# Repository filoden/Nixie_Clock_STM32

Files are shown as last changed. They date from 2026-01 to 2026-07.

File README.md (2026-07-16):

# Nixie_Clock_STM32

An STM32-based **Nixie-tube alarm clock** (HH:MM) with audio, SD storage, and a custom enclosure. 
Repository still in developement.

> ⚠️ **High Voltage Warning**
> Nixie tubes require a high-voltage supply (~170VDC for IN-12 used in this project). Basic HV safety knowledge is necessary to avoid injury and or death.

---

## Project Snapshot

**Design tools:** KiCad (PCB), STM32CubeMX / STM32CubeIDE (firmware), SolidWorks (enclosure)

**Repo structure**
- `Current Iteration/` – active hardware + firmware
  - `Current Iteration/Enclosure`
  - `Current Iteration/STM32 Project Files and Code`
  - `Current Iteration/Schematic Layout & PCB`
- `Old_Versions/` – previous spins / archived work

---

## Features

### Hardware / Electronics (status)
**In development**
- low power / battery-power mode
- Oscillator bring-up / stability checks

**Tested (prototype version)**
- Capacitive touch input

**Finalized**
- I2S audio communication
- 5V → 12V boost 
- SPI / I2C communication
- SD Card Interface
- Rotary encoders
- 5V → 3.3V LDO
- Audio output: driving a 4Ω speaker through the MAX98567A (except for bulk cap)
- SD audio file reading

---

## Hardware Overview (high level)

- **MCU:** STM32G0B1RETx6
- **UX/UI:** rotary encoder(s) (One encouder includes a push button), capacitive touch
- **Timekeeping:** STM32 RTC + external LSE oscillator
- **Storage:** microSD over SPI (FatFs)
- **Audio:** I2S to class-D amp (MAX98567A) → 4Ω speaker
- **Driving Nixie Tubes** STM MCU drives serial into a 12V level shifter which drives HV5622PG chips. These chips switch the tubes using an external 170V DC source.
- **Capacitive touch senor** Conductive edge banding surrounds large portions of controller. CAP1206 IC interprets changes in banding capacitance and communicates over I2C to MCU.
- **Power:**
  - USB-C 5V input (mechanical + ESD considerations)
  - 5V enters Linear low-dropout regulator -> 3.3V 
  - 3.3V rail for logic
  - HV rail for Nixie tubes (external boost converter)
  - Battery backup is used for logic, oscillator, amplifier, and capacitive touch sensor in the event of 5V loss
  - Battery and 3.3V power is controlled using NID5100, low-forward voltage drop diodes.
### Schematic Preview
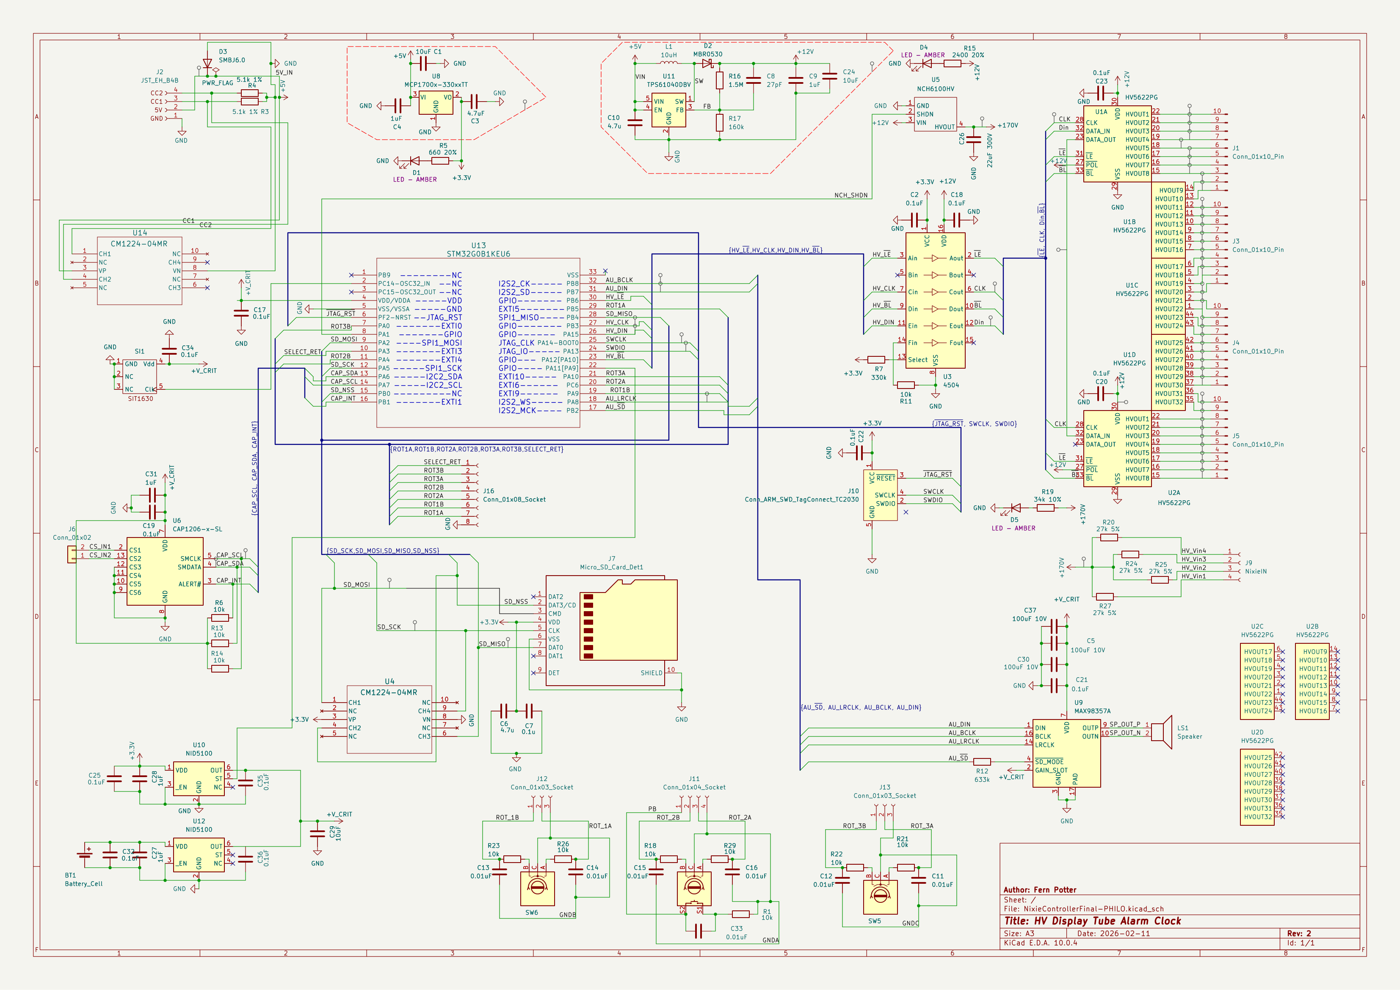
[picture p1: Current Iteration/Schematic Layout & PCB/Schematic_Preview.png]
Schematic

### Block Diagram
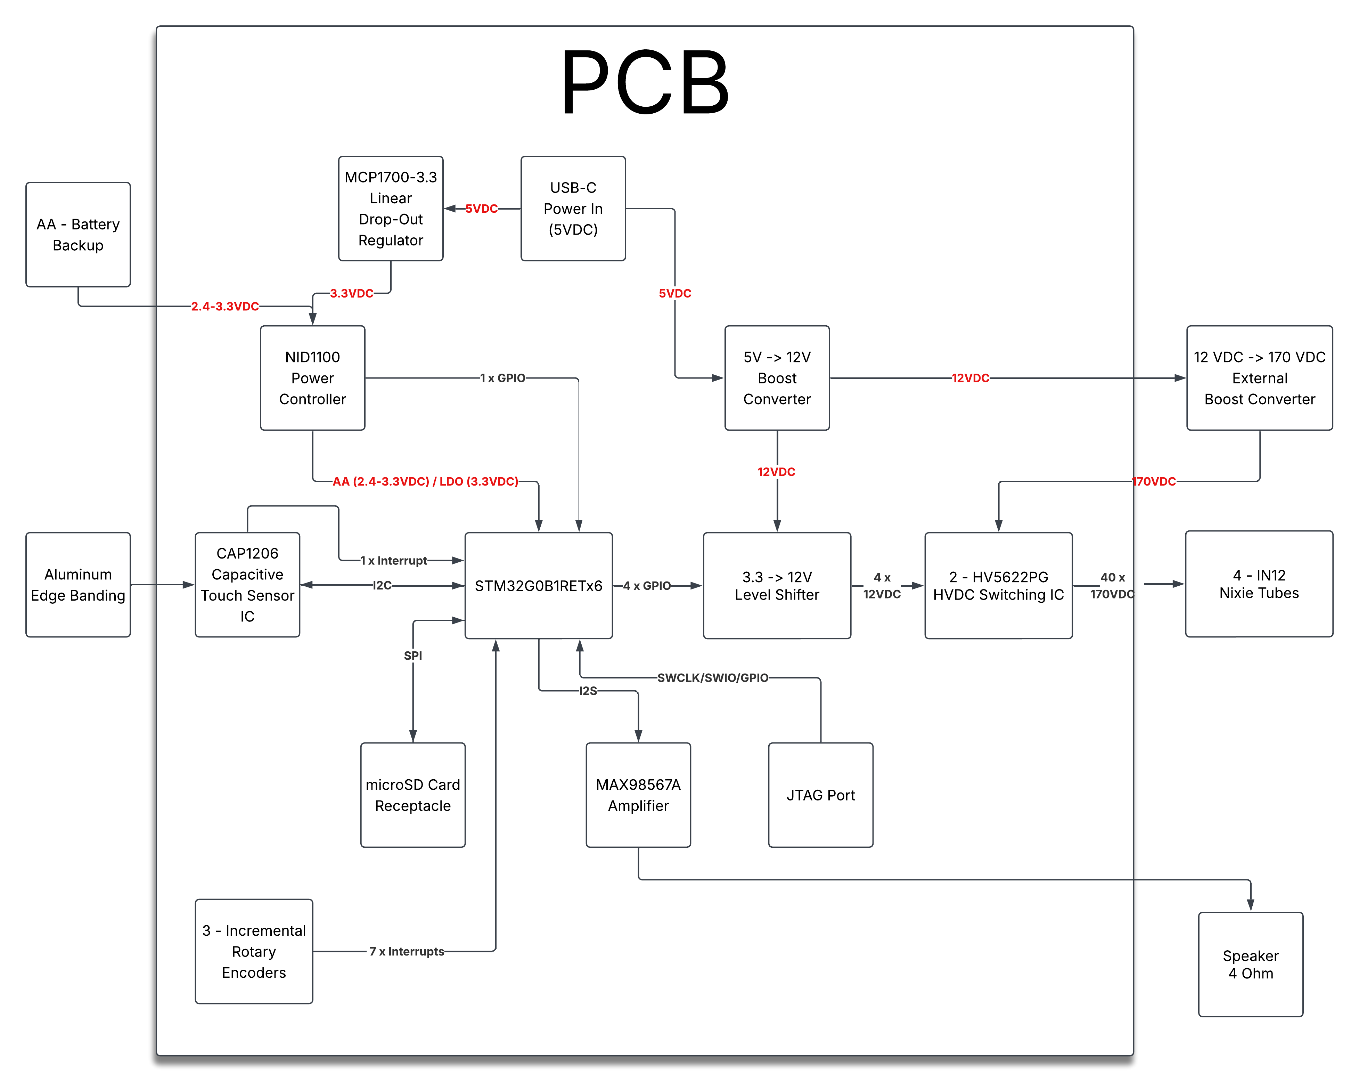
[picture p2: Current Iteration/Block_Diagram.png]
Block Diagram

#### Notes:
- All Power lines are written in red text
- Arrow direction denotes either flow of power or data (although JTAG should be bidirectional)
- Ground for IN12 Tubes is omitted
---

## Firmware 
### Build / Flash 
1. Open the firmware project in **STM32CubeIDE**.
2. Confirm CubeMX-generated peripherals match the board wiring (SPI for SD, I2S for audio, GPIO/EXTI for inputs). Make sure to include separate driver files for FATFS (Provided by CubeMX). 
4. Build + flash via **ST-LINK**.
5. To avoid frustration, bring-up in this order:
### Firmware Development (Status):
### Integration:
**1. UI FSM**
- UI is structured as an FSM. Programmatically each input will trigger a user-input function for each respective input (knob A turns CC, knob B turns C, etc.. Each function consists of a long switch case which maps the appropriate response to an input for a given state. Relevant code is in UserInterface source and header files. FSM can be seen below.
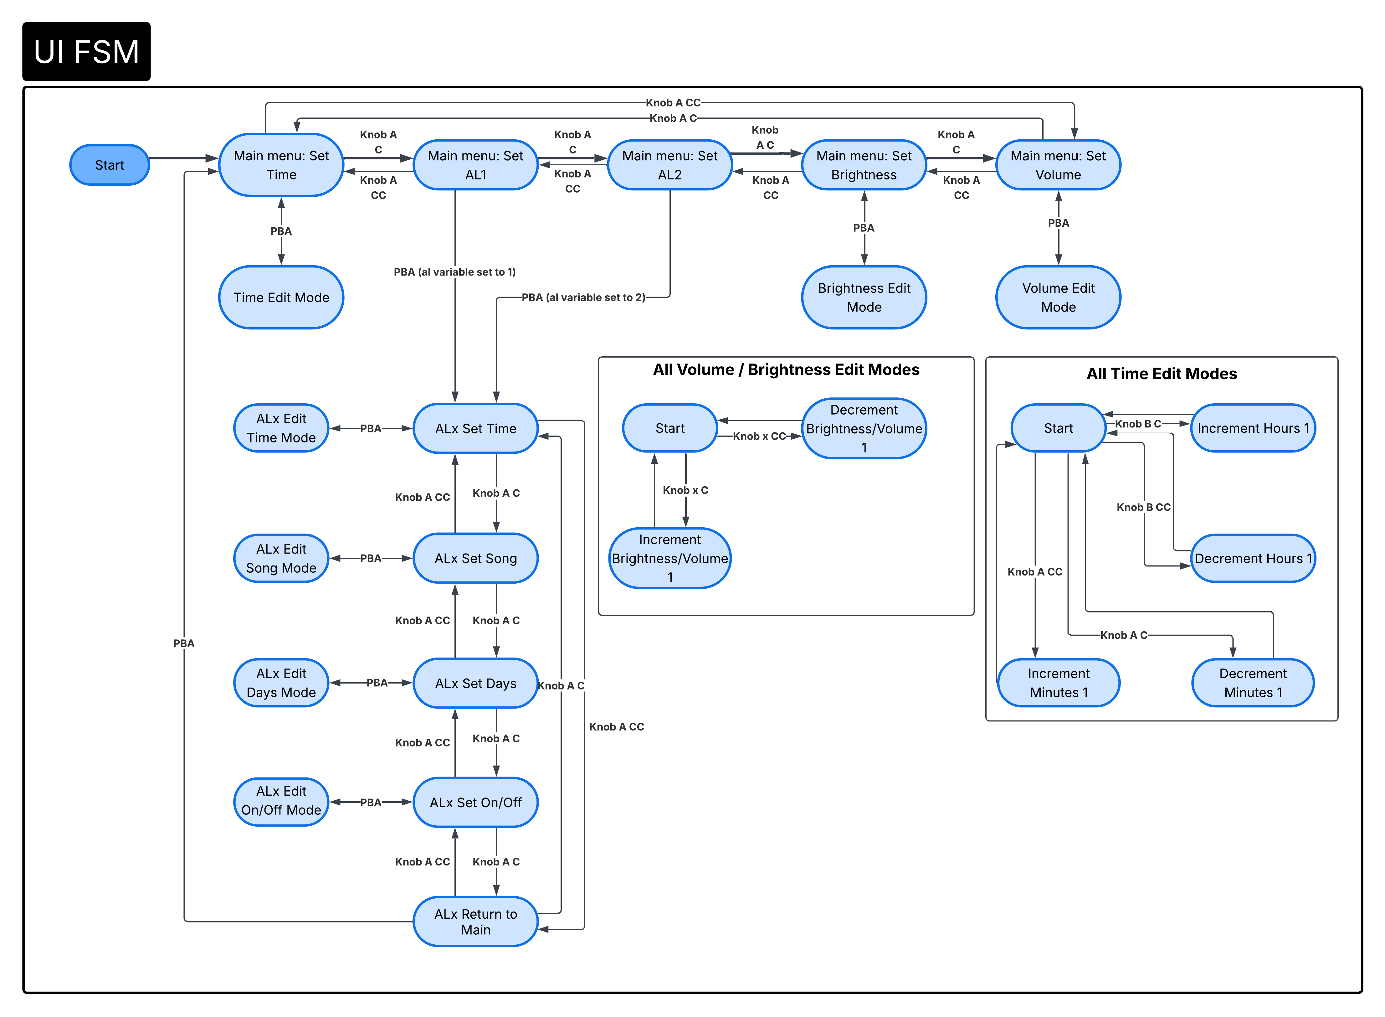
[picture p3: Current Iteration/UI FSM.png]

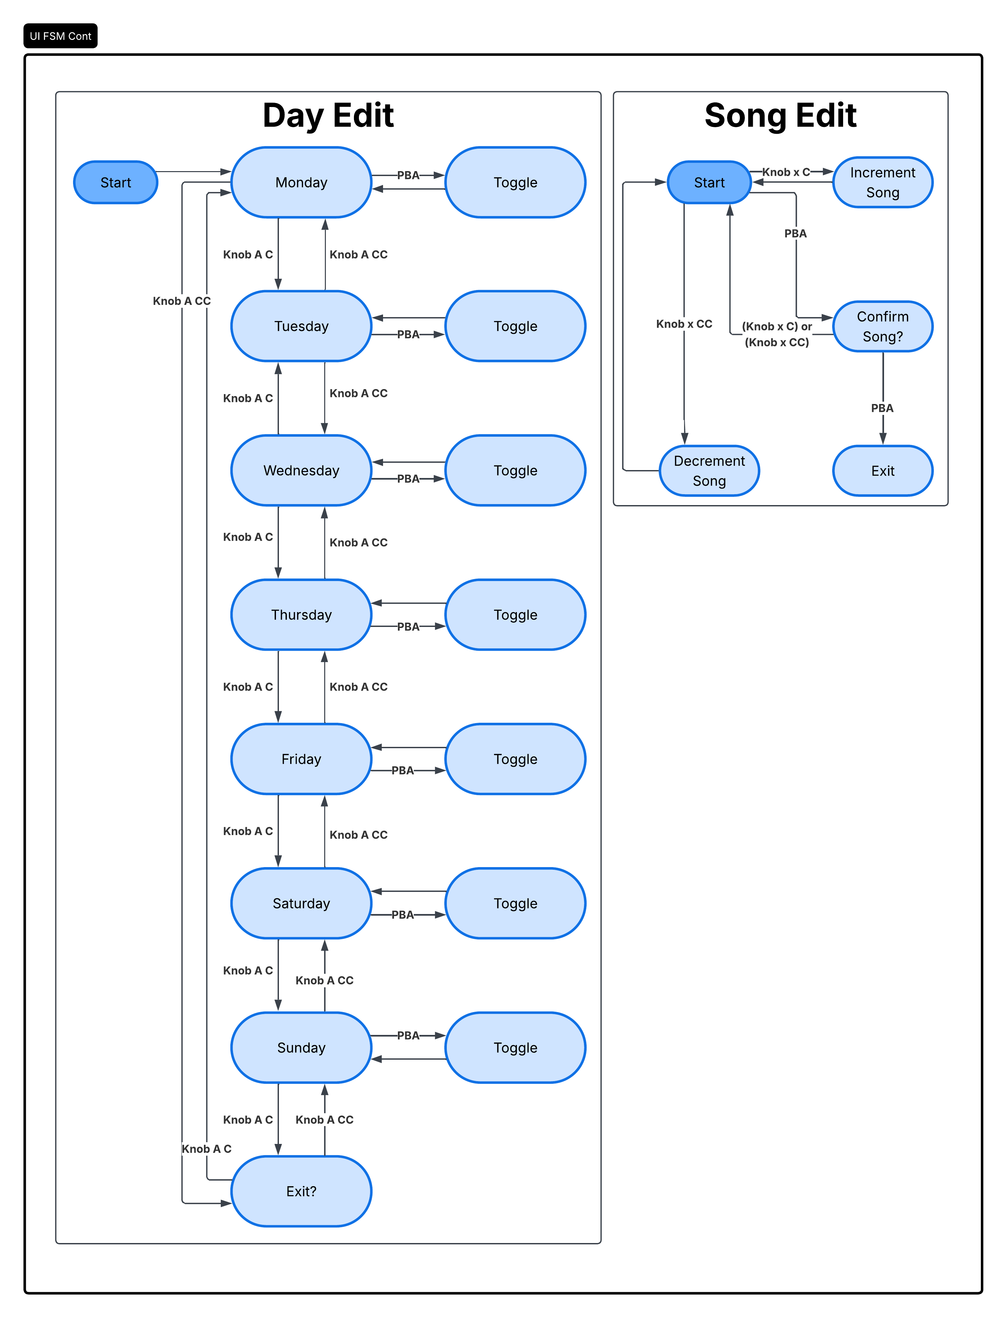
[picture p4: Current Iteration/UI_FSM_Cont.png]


**Notes to come:**

**2. DMA music playing**

**3. SD card interface**

**4. Capacitive touch sensor**

**5. Music FIle Parsing**

### In development:

**6. Nixie driver control logic**

- Nixie tubes require 170VDC switching. Thankfully, Many old display tubes and other vintage electronics require high voltage DC. Since there is still demand for this technology an old (relatively speaking) serial to parallel high voltage switching IC known as the HV5622PG is still in production. This $8 chip can handle up to 250VDC and requires a ridiculous 12V logic level. The Nixie driver control logic tells this chip which digits to turn on. Importantly, it must also make sure that no more than one digit is driven at a time, as this can easily destroy the tube. Additionally, it is necesary to include PWM control to allow for dimming, and to be easily accessible by other parts of the code.
- Requirements: 
  - Checks to ensure there is no double digit driving
  - Dimming Control
  - Simple function call

**7. Low-Power (Blackout) Handling**

Requirements:
  - Set Pins to LOW (Remove any Pullups as well): Nixie Driving GPIO, JTAG, SD_CARD, CAP1206, knobs B/C
  - Following Interfaces to remain as normal: MAX98357A
  - Sense Power-outage via ST pin on NID5100
  - Be able to play low power alarm song stored solely in on-chip memory

**8. New external LSE with RTC implementation**

Requirements:
  - Initialization
  - Maintain RTC control through momentary resets
  - Calibration (?)
---

## PCB Development
Current version consists of a single main board with three separate smaller boards (separated by user) for the rotary encoder circuitry.
- **V1 PCB:** learning spin (many layout mistakes)
- **V2 PCB:** More fully built out, includes all relevent IO.
- **V3 PCB:** pending completion of wiring/programming development - most up to date version located in current iteration. 
### To-do
- External LSE oscillator testing
- Add AA discharge protection
- Connext NCH6100HV Directly to 5V rail instead of 12V
- Much more
### PCB Preview
**V3 PCB:**
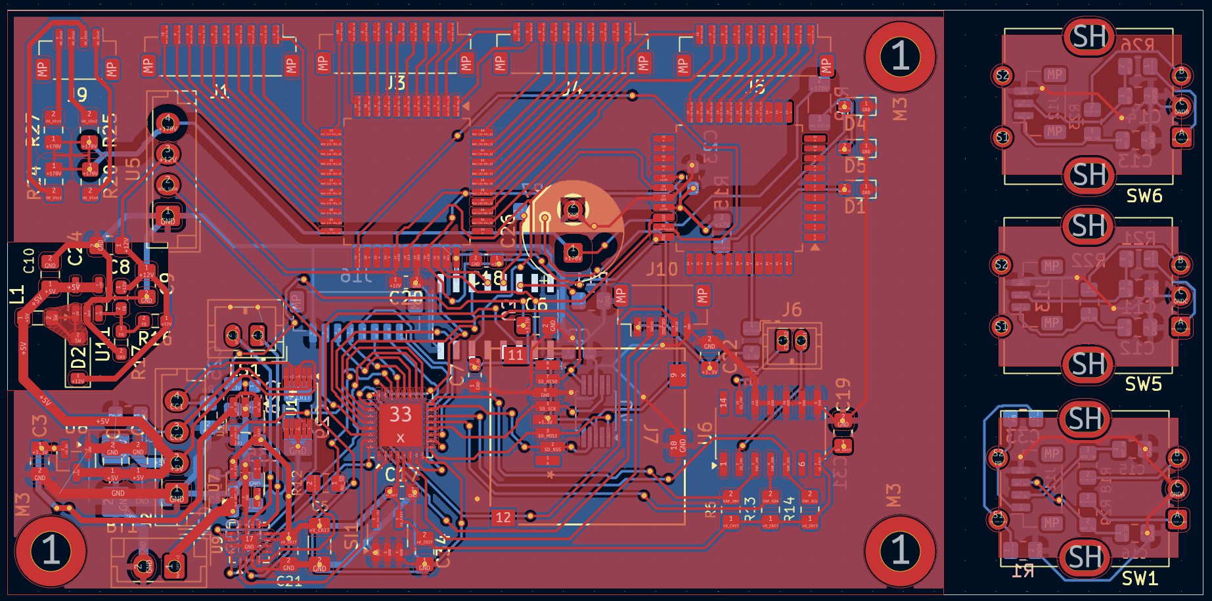
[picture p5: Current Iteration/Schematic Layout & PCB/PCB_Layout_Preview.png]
Current Revision
 
---

## Enclosure Development

### Current plan
- Mostly **wood** enclosure in **two glued halves**
- Two halves are **mostly symmetric** and CNC-machinable from a single board  
  - Best results: mill one thick piece and split for mirrored grain (book-matching)
- **Front + back edges:** laser-cut **aluminum edge banding** (strength + aesthetics), glued in place
- **Back plate:** thicker aluminum for rotary encoders + USB-C inlet
- **Front plate:** 1/8" glass (waterjet preferred; hand-fab possible) with a grey tint

### To-do
- Vector files: back plate, glass face, edge banding
- Finalize BOM
- Investigate use of waterjet for glass face
### Enclosure Preview
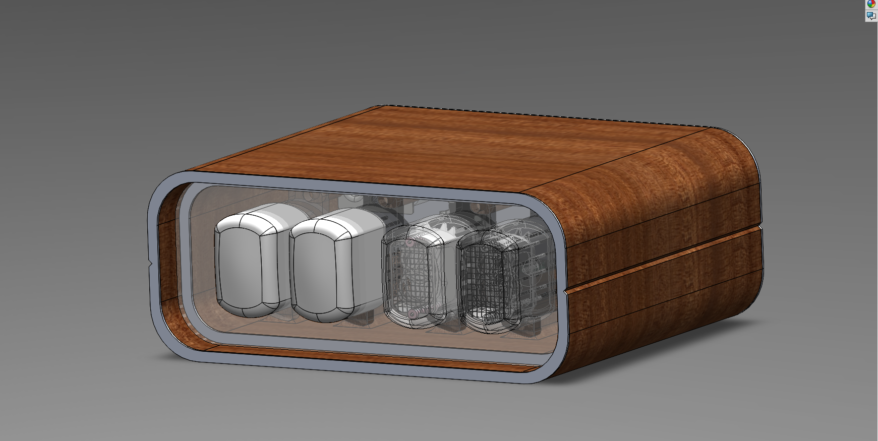
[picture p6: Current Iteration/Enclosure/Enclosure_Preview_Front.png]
Enclosure Front

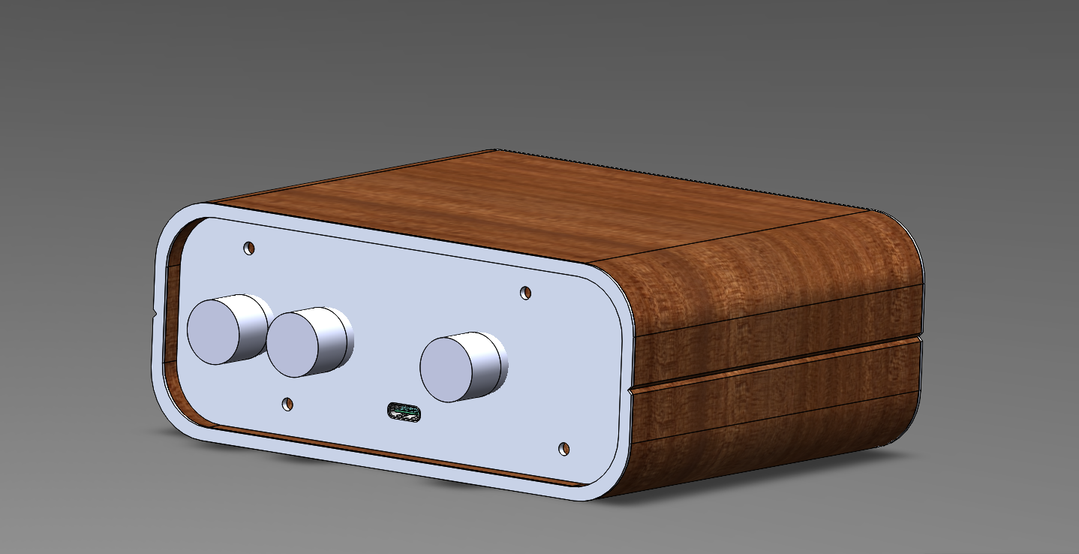
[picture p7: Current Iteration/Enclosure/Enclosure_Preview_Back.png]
Enclosure Back

---

## BOM
- PCB BOM currently matches latest revision
- Enclosure BOM is out of date

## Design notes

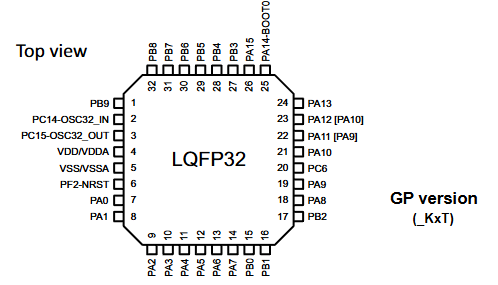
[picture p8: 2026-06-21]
Useful Documents/Pinout_STM32G0B1RET6-LQFP32.png

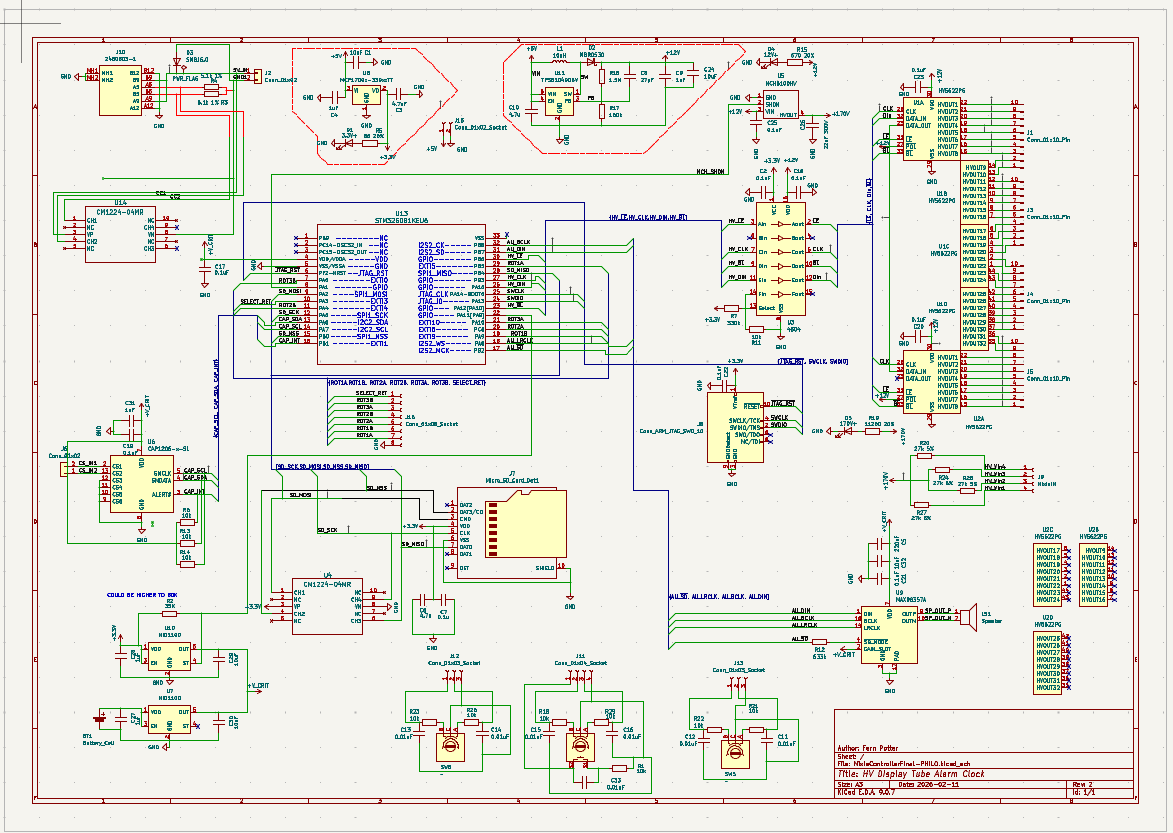
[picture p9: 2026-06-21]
Current Iteration/Schematic Layout & PCB/Schematic_Layout_Preview.png

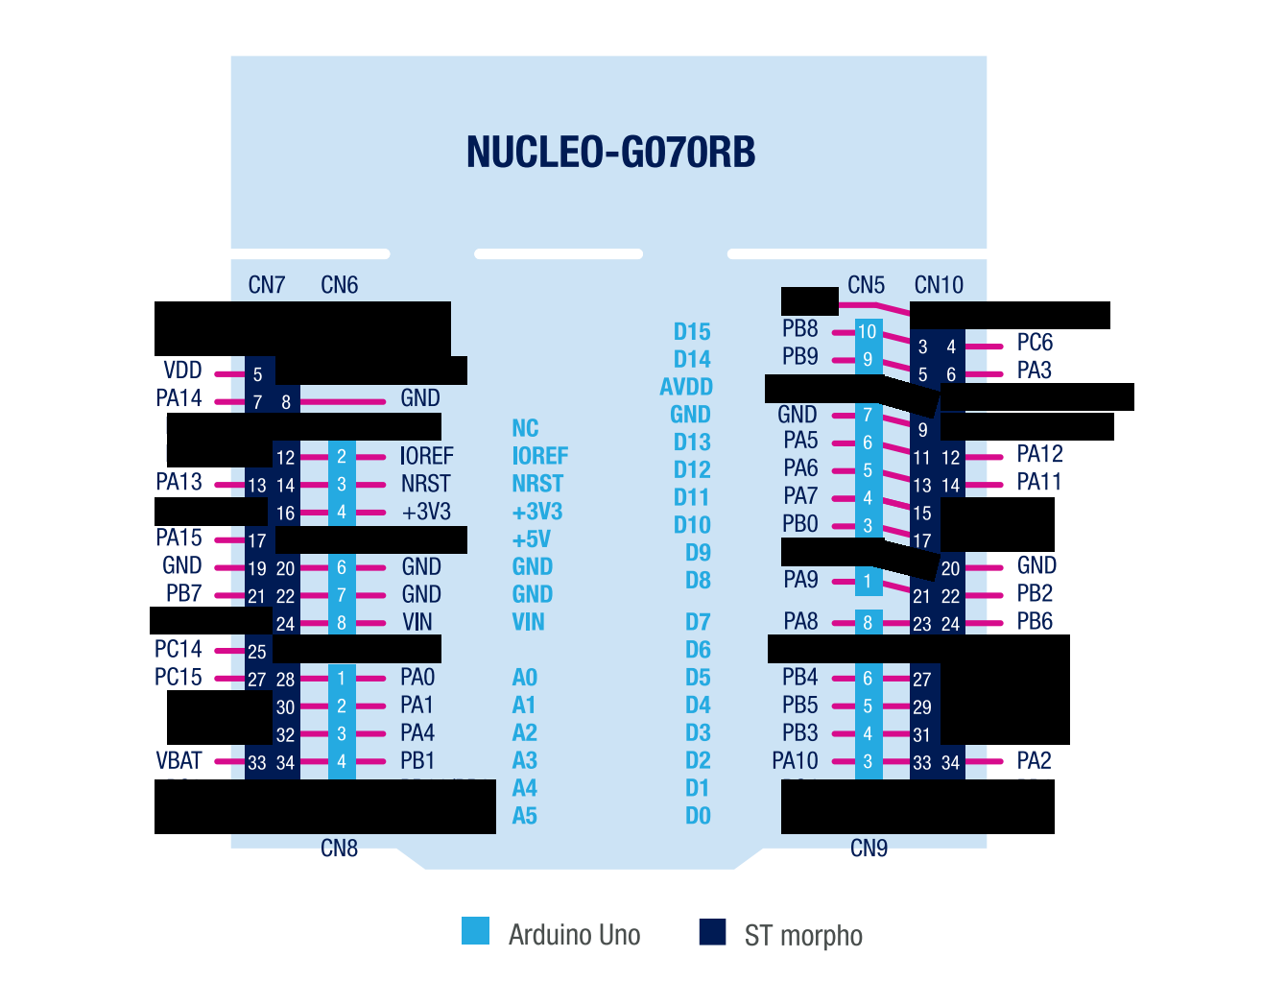
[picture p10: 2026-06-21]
Useful Documents/Pinout_Nucleo_G0B1RE.png

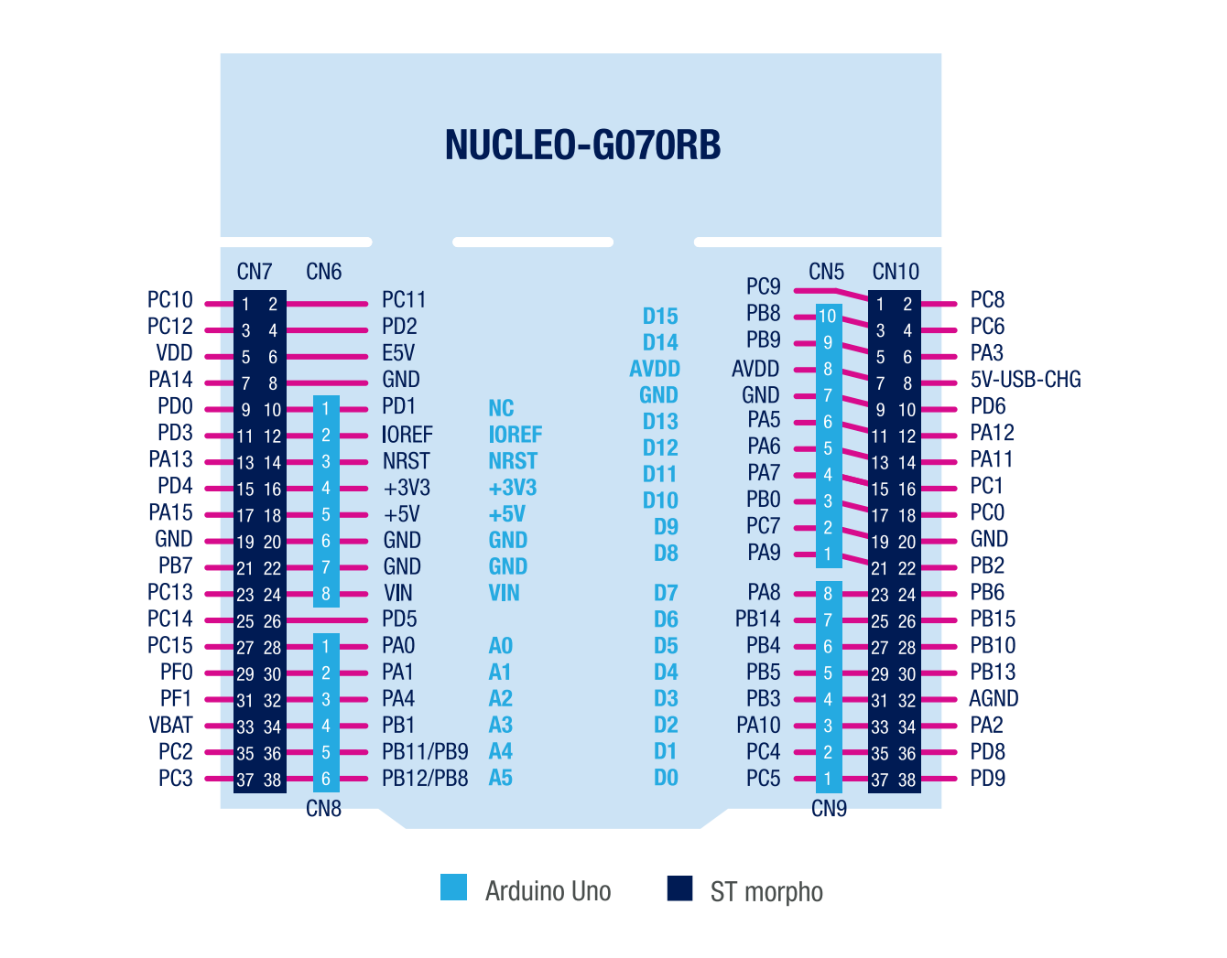
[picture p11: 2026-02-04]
Useful Documents/Screenshot 2026-01-30 183604.png

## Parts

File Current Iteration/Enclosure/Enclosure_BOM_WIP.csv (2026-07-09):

Quantity | Part
1 | 4x6x10 (inches) hard wood of choice
1 | 6x12 1/16 (inches) aluminum sheeting
4 | IN12 New Old Stock Nixie Tubes

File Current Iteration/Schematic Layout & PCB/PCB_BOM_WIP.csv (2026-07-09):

Reference | Qty | Value | DNP | Exclude from BOM | Exclude from Board | Footprint | Datasheet
BT1 | 1 | Battery_Cell |  |  |  | Connector_JST:JST_EH_B2B-EH-A_1x02_P2.50mm_Vertical | ~
C1,C29,C30 | 3 | 10uF |  |  |  | Capacitor_SMD:C_0805_2012Metric_Pad1.18x1.45mm_HandSolder | ~
C2,C17,C18,C19,C21,C22,C25 | 7 | 0.1uF |  |  |  | Capacitor_SMD:C_0805_2012Metric_Pad1.18x1.45mm_HandSolder | ~
C3 | 1 | 4.7uF |  |  |  | Capacitor_SMD:C_0805_2012Metric_Pad1.18x1.45mm_HandSolder | ~
C4,C9,C27,C28,C31 | 5 | 1uF |  |  |  | Capacitor_SMD:C_0805_2012Metric_Pad1.18x1.45mm_HandSolder | ~
C5 | 1 | 220uF |  |  |  | Capacitor_SMD:C_1206_3216Metric_Pad1.33x1.80mm_HandSolder | ~
C6 | 1 | 4.7u |  |  |  | Capacitor_SMD:C_1206_3216Metric_Pad1.33x1.80mm_HandSolder | ~
C7 | 1 | 0.1u |  |  |  | Capacitor_SMD:C_0805_2012Metric_Pad1.18x1.45mm_HandSolder | ~
C8 | 1 | 27pF |  |  |  | Capacitor_SMD:C_0805_2012Metric_Pad1.18x1.45mm_HandSolder | ~
C10 | 1 | 4.7u |  |  |  | Capacitor_SMD:C_0805_2012Metric_Pad1.18x1.45mm_HandSolder | ~
C11,C12,C13,C14,C15,C16,C33 | 7 | 0.01uF |  |  |  | Capacitor_SMD:C_0805_2012Metric_Pad1.18x1.45mm_HandSolder | ~
C20,C23 | 2 | 0.1uF |  |  |  | Capacitor_SMD:C_1808_4520Metric_Pad1.72x2.30mm_HandSolder | ~
C24,C32 | 2 | 10uF |  |  |  | Capacitor_SMD:C_1206_3216Metric_Pad1.33x1.80mm_HandSolder | ~
C26 | 1 | 22uF 300V |  |  |  | Capacitor_THT:CP_Radial_D8.0mm_P3.50mm | ~
D1 | 1 | 3.3V+ |  |  |  | LED_SMD:LED_0603_1608Metric_Pad1.05x0.95mm_HandSolder | ~
D2 | 1 | MBR0530 |  |  |  | Diode_SMD:D_SOD-123 | http://www.mccsemi.com/up_pdf/MBR0520~MBR0580(SOD123).pdf
D3 | 1 | SMBJ6.0 |  |  |  | Diode_SMD:D_SMB | ~
D4 | 1 | 12V+ |  |  |  | LED_SMD:LED_0603_1608Metric_Pad1.05x0.95mm_HandSolder | ~
D5 | 1 | 170V+ |  |  |  | LED_SMD:LED_0603_1608Metric_Pad1.05x0.95mm_HandSolder | ~
J1,J3,J4,J5 | 4 | Conn_01x10_Pin |  |  |  | Connector_JST:JST_SH_BM10B-SRSS-TB_1x10-1MP_P1.00mm_Vertical | ~
J2 | 1 | Conn_01x02 |  |  |  |  | ~
J6 | 1 | Conn_01x02 |  |  |  | Connector_JST:JST_EH_B2B-EH-A_1x02_P2.50mm_Vertical | ~
J7 | 1 | Micro_SD_Card_Det1 |  |  |  | footprints:MEM2061-01-188-00-A_GCT | https://datasheet.lcsc.com/lcsc/2110151630_XKB-Connectivity-XKTF-015-N_C381082.pdf
J8 | 1 | Conn_ARM_JTAG_SWD_10 |  |  |  | Connector_JST:JST_SH_BM05B-SRSS-TB_1x05-1MP_P1.00mm_Vertical | http://infocenter.arm.com/help/topic/com.arm.doc.ddi0314h/DDI0314H_coresight_components_trm.pdf
J9 | 1 | NixieIN |  |  |  | Connector_JST:JST_SH_BM04B-SRSS-TB_1x04-1MP_P1.00mm_Vertical | ~
J10 | 1 | 2480803-1 |  |  |  | Connector_USB:24808031 | https://www.te.com/de/product-2480803-1.datasheet.pdf
J11 | 1 | Conn_01x04_Socket |  |  |  | Connector_JST:JST_SH_BM04B-SRSS-TB_1x04-1MP_P1.00mm_Vertical | ~
J12,J13 | 2 | Conn_01x03_Socket |  |  |  | Connector_JST:JST_SH_BM03B-SRSS-TB_1x03-1MP_P1.00mm_Vertical | ~
J15 | 1 | Conn_01x02_Socket |  |  |  | Connector_JST:JST_EH_B2B-EH-A_1x02_P2.50mm_Vertical | ~
J16 | 1 | Conn_01x08_Socket |  |  |  | Connector_JST:JST_SH_BM08B-SRSS-TB_1x08-1MP_P1.00mm_Vertical | ~
L1 | 1 | 10uH |  |  |  | Inductor_SMD:L_0805_2012Metric_Pad1.05x1.20mm_HandSolder | ~
LS1 | 1 | Speaker |  |  |  | Connector_JST:JST_PH_B2B-PH-K_1x02_P2.00mm_Vertical | ~
R1,R6,R11,R13,R14,R18,R21,R22,R23,R26,R29 | 11 | 10k |  |  |  | Resistor_SMD:R_0805_2012Metric_Pad1.20x1.40mm_HandSolder | ~
R2 | 1 | 35K |  |  |  | Resistor_SMD:R_0805_2012Metric_Pad1.20x1.40mm_HandSolder | ~
R3,R4 | 2 | 5.1k 1% |  |  |  | Resistor_SMD:R_0805_2012Metric_Pad1.20x1.40mm_HandSolder | ~
R5 | 1 | 86 20% |  |  |  | Resistor_SMD:R_0805_2012Metric_Pad1.20x1.40mm_HandSolder | ~
R7 | 1 | 330k |  |  |  | Resistor_SMD:R_0805_2012Metric_Pad1.20x1.40mm_HandSolder | ~
R12 | 1 | 633k |  |  |  | Resistor_SMD:R_0805_2012Metric_Pad1.20x1.40mm_HandSolder | ~
R15 | 1 | 670 20% |  |  |  | Resistor_SMD:R_0805_2012Metric_Pad1.20x1.40mm_HandSolder | ~
R16 | 1 | 1.5M |  |  |  | Resistor_SMD:R_0805_2012Metric_Pad1.20x1.40mm_HandSolder | ~
R17 | 1 | 160k |  |  |  | Resistor_SMD:R_0805_2012Metric_Pad1.20x1.40mm_HandSolder | ~
R19 | 1 | 11200 20% |  |  |  | Resistor_SMD:R_0805_2012Metric_Pad1.20x1.40mm_HandSolder | ~
R20,R24,R25,R27 | 4 | 27k 5% |  |  |  | Resistor_SMD:R_0805_2012Metric_Pad1.20x1.40mm_HandSolder | ~
SW1,SW5,SW6 | 3 | ~ |  |  |  | Rotary_Encoder:RotaryEncoder_Bourns_Vertical_PEC12R-3x17F-Sxxxx | kicad-embed://PEC11J.pdf,kicad-embed://pec16.pdf
U1,U2 | 2 | HV5622PG |  |  |  | Package_QFP:PQFP-44_10x10mm_P0.8mm | https://ww1.microchip.com/downloads/aemDocuments/documents/OTH/ProductDocuments/DataSheets/20005854A.pdf
U3 | 1 | 4504 |  |  |  | footprints:SOIC-16_ONS | http://www.ti.com/lit/ds/symlink/cd4504b.pdf
U4,U14 | 2 | CM1224-04MR |  |  |  | Package_SO:MSOP-10_3x3mm_P0.5mm | CM1224-04MR
U5 | 1 | NCH6100HV |  |  |  | Connector_JST:JST_EH_B4B-EH-A_1x04_P2.50mm_Vertical | kicad-embed://NIXIE-Power-Supply-Datasheet-EN-v1.0.0.pdf
U6 | 1 | CAP1206-x-SL |  |  |  | Package_SO:SOIC-14_3.9x8.7mm_P1.27mm | http://ww1.microchip.com/downloads/en/DeviceDoc/00001567B.pdf
U7,U10 | 2 | NID1100 |  |  |  | Package_TO_SOT_SMD:SC-74A-5_1.55x2.9mm_P0.95mm | https://assets.nexperia.com/documents/data-sheet/NID1100.pdf
U8 | 1 | MCP1700x-330xxTT |  |  |  | Package_TO_SOT_SMD:SOT-23 | http://ww1.microchip.com/downloads/en/DeviceDoc/20001826D.pdf
U9 | 1 | MAX98357A |  |  |  | Package_DFN_QFN:TQFN-16-1EP_3x3mm_P0.5mm_EP1.23x1.23mm | https://www.analog.com/media/en/technical-documentation/data-sheets/MAX98357A-MAX98357B.pdf
U11 | 1 | TPS61040DBV |  |  |  | Package_TO_SOT_SMD:SOT-23-5 | http://www.ti.com/lit/ds/symlink/tps61040.pdf
U13 | 1 | STM32G0B1KEU6 |  |  |  | Package_DFN_QFN:UFQFPN-32-1EP_5x5mm_P0.5mm_EP3.5x3.5mm | https://www.st.com/resource/en/datasheet/stm32g0b1cc.pdf

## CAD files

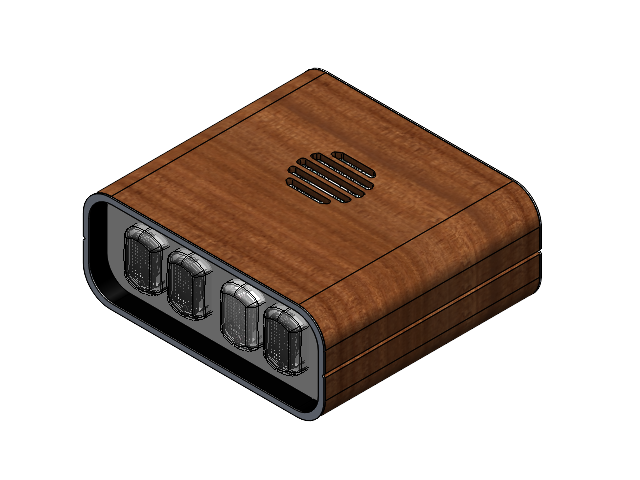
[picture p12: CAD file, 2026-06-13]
Current Iteration/Enclosure/Enclosure.SLDASM
IN-12 nixie tube glass body.STEP x 4
IN-12 nixie tube pin.STEP x 48
IN-12 nixie tube anode grid.STEP x 4
IN-12 nixie tube 0 digit.STEP x 4
IN-12 nixie tube 1 digit.STEP x 4
IN-12 nixie tube 2 digit.STEP x 4
IN-12 nixie tube 3 digit.STEP x 4
IN-12 nixie tube 4 digit.STEP x 4
IN-12 nixie tube 5 digit.STEP x 4
IN-12 nixie tube 6 digit.STEP x 4
IN-12 nixie tube 7 digit.STEP x 4
IN-12 nixie tube 8 digit.STEP x 4
IN-12 nixie tube 9 digit.STEP x 4
IN-12 nixie tube spacer.STEP x 96
IN-12 nixie tube rod.STEP x 8
IN-12 nixie tube back plate 1.STEP x 4
IN-12 nixie tube back plate 2.STEP x 4
MainEnclosure^NixieClock2
Copy of User Library-PL31Ap^NixieClock2 x 4
Frontmost Edge Banding^NixieClock2
Rear Edge Banding^NixieClock2
Smaller Edge Banding Front^NixieClock2
Switch-PEC11J^NixieClock2 x 3
Knob Model^NixieClock2 x 3
Copy of Studio-R4 CAD Props_Battery-AAA^NixieClock2 x 2
Glass Face^NixieClock2
Speaker
240-004-BR x 13
Part5^NixieClock2

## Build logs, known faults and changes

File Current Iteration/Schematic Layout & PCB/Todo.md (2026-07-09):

# Next Revision:

## PCB/Schematic:
1. Find in production alternative to HV5622PG
2. Replace MAX98357A bulk capacitance with a single electrolytic cap

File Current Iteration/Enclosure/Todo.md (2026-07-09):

# Todo
1. Import PCB 3-D model to ensure compatibility (waiting on PCB finilized)
2. BOM
3. Investigate a source for custom glass face

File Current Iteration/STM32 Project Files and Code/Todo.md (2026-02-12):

# Programming Todo:
1. Low power mode entering / exiting
2. FSM for main operation loop and implementation
3. Oscillator / RTC implementation

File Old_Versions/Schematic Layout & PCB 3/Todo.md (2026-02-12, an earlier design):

# Todo:

## PCB:
1. USB-C port should be incorporated into main PCB,may result in small size increase
2. Rotary encoders require seperate PCB with JST jack, main PCB will need a new JST jack as well

## Schematic:
1. Oscillator/RTC module incorporation

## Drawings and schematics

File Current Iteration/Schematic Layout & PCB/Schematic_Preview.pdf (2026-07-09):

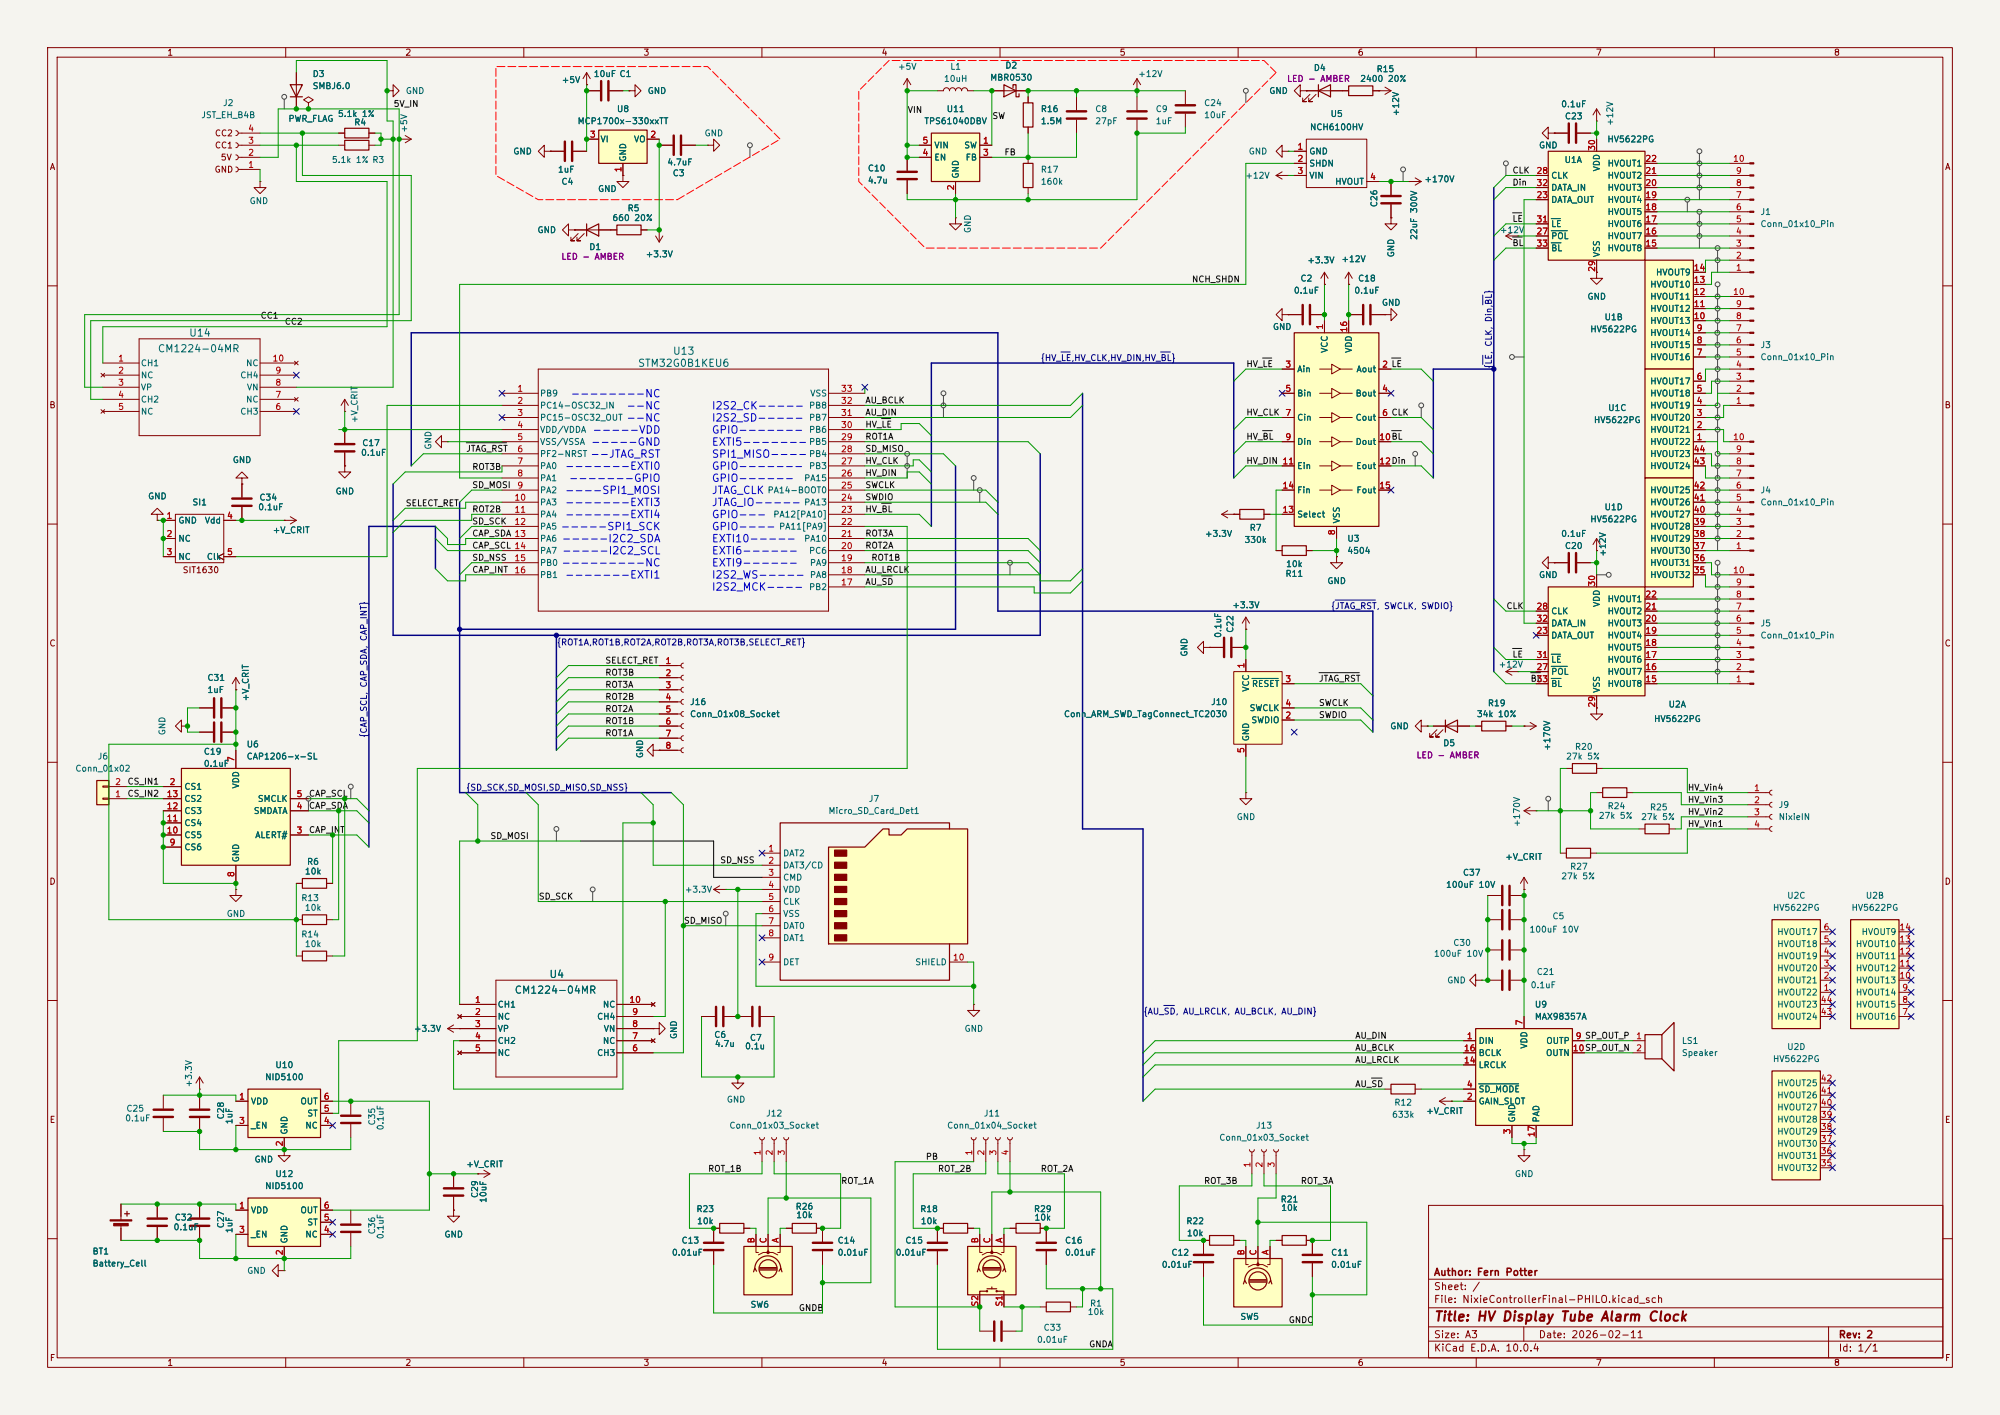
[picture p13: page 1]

{LE, CLK, Din,BL} Din

Sheet: /
File: NixieControllerFinal-PHILO.kicad_sch
Title: HV Display Tube Alarm Clock

Size: A3 | Rev: 2
KiCad E.D.A. 10.0.4 | Id: 1/1 | F Date: 2026-02-11

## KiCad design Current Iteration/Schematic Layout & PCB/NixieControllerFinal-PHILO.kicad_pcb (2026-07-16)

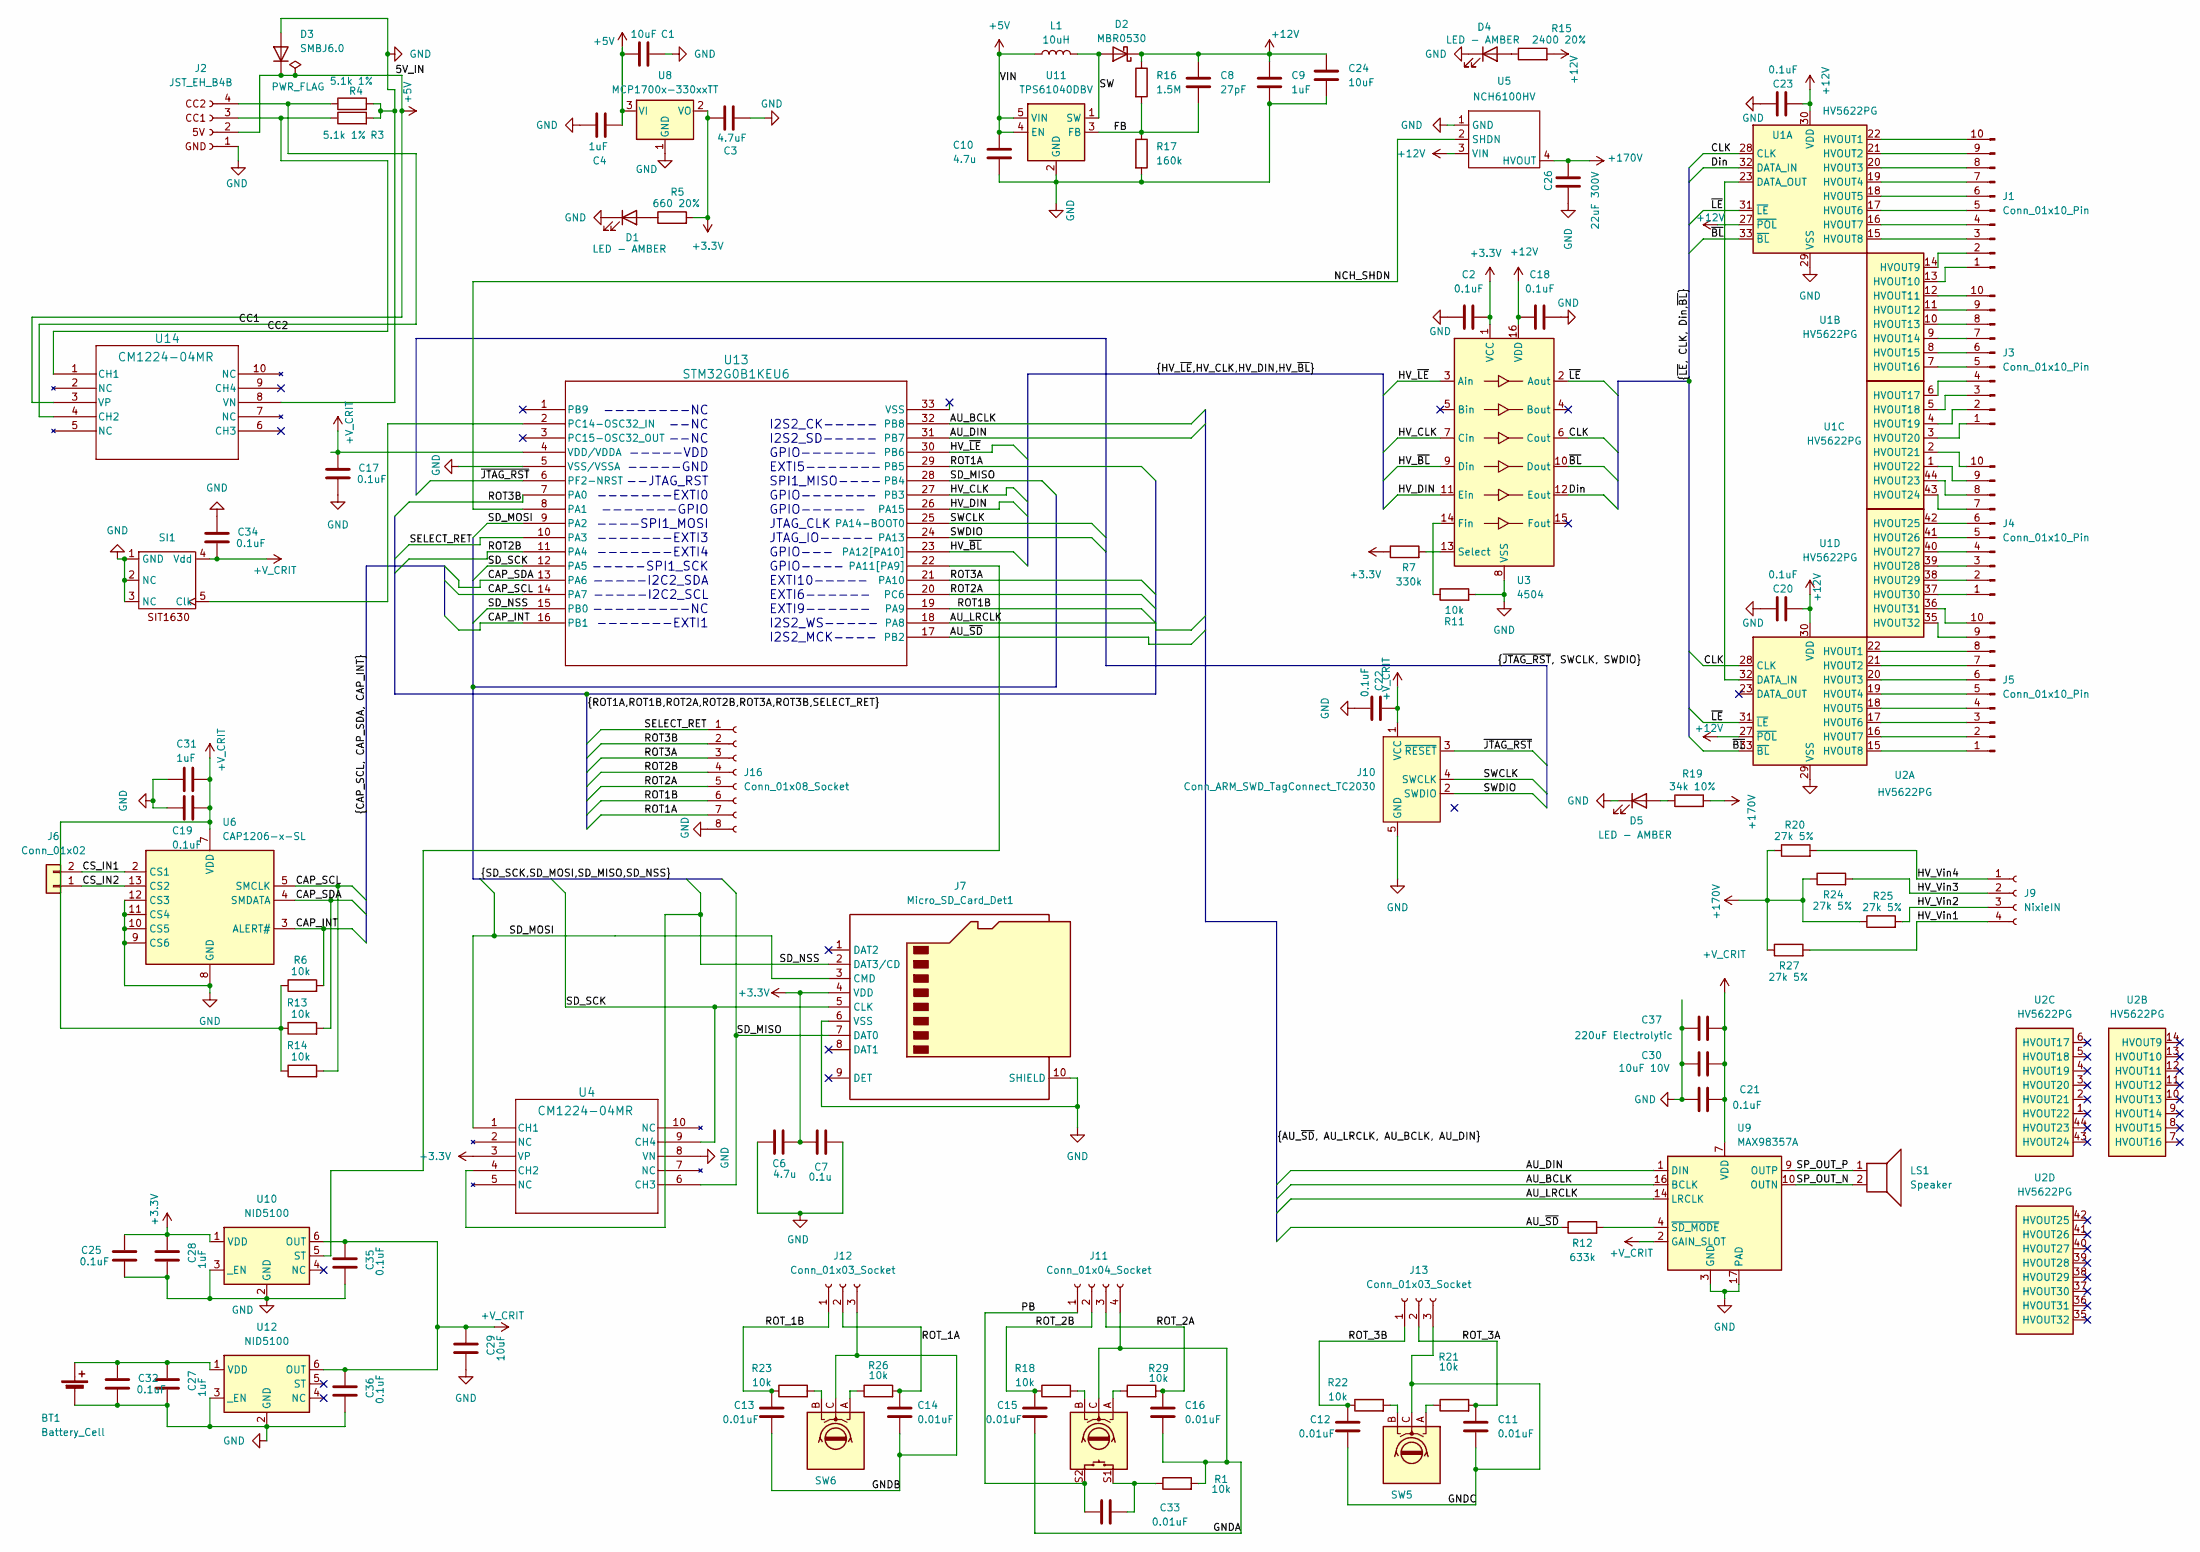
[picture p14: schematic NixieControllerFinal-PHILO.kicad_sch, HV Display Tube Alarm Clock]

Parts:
BT1: Battery_Cell; JST_EH_B2B-EH-A_1x02_P2.50mm_Vertical
C1, C24: 10uF; C_0805_2012Metric_Pad1.18x1.45mm_HandSolder
C2, C17, C18, C20, C21, C23, C25, C32, C35, C36: 0.1uF; C_0603_1608Metric_Pad1.08x0.95mm_HandSolder
C3: 4.7uF; C_0805_2012Metric_Pad1.18x1.45mm_HandSolder
C4, C9, C27, C28, C31: 1uF; C_0805_2012Metric_Pad1.18x1.45mm_HandSolder
C6, C10: 4.7u; C_0805_2012Metric_Pad1.18x1.45mm_HandSolder
C7: 0.1u; C_0603_1608Metric_Pad1.08x0.95mm_HandSolder
C8: 27pF; C_0603_1608Metric_Pad1.08x0.95mm_HandSolder
C11, C12, C13, C14, C15, C16, C33: 0.01uF; C_0805_2012Metric_Pad1.18x1.45mm_HandSolder
C19, C22, C34: 0.1uF; C_0805_2012Metric_Pad1.18x1.45mm_HandSolder
C26: 22uF 300V; CP_Radial_D8.0mm_P3.50mm
C29: 10uF; C_1206_3216Metric_Pad1.33x1.80mm_HandSolder
C30: 10uF 10V; C_0603_1608Metric_Pad1.08x0.95mm_HandSolder
C37: 220uF Electrolytic; CP_Radial_D5.0mm_P2.00mm
D1, D4, D5: 150060AS75000; LED_0603_1608Metric_Pad1.05x0.95mm_HandSolder
D2: MBR0530; D_SOD-123
D3: SMBJ6.0; D_SMB
J1, J3, J4, J5: Conn_01x10_Pin; JST_SH_BM10B-SRSS-TB_1x10-1MP_P1.00mm_Vertical
J2: JST_EH_B4B; JST_EH_B4B-EH-A_1x04_P2.50mm_Vertical
J6: Conn_01x02; JST_PH_B2B-PH-K_1x02_P2.00mm_Vertical
J7: Micro_SD_Card_Det1; microSD_HC_Molex_104031-0811
J9: NixieIN; JST_SH_BM04B-SRSS-TB_1x04-1MP_P1.00mm_Vertical
J10: Conn_ARM_SWD_TagConnect_TC2030; PinHeader_1x05_P2.54mm_Vertical
J11: Conn_01x04_Socket; JST_SH_BM04B-SRSS-TB_1x04-1MP_P1.00mm_Vertical
J12, J13: Conn_01x03_Socket; JST_SH_BM03B-SRSS-TB_1x03-1MP_P1.00mm_Vertical
J16: Conn_01x08_Socket; JST_SH_BM08B-SRSS-TB_1x08-1MP_P1.00mm_Vertical
L1: 10uH; L_0805_2012Metric_Pad1.05x1.20mm_HandSolder
LS1: Speaker; JST_PH_B2B-PH-K_1x02_P2.00mm_Vertical
R1, R6, R11, R13, R14, R18, R21, R22, R23, R26, R29: 10k; R_0805_2012Metric_Pad1.20x1.40mm_HandSolder
R3, R4: 5.1k 1%; R_0805_2012Metric_Pad1.20x1.40mm_HandSolder
R5: 660 20%; R_0805_2012Metric_Pad1.20x1.40mm_HandSolder
R7: 330k; R_0805_2012Metric_Pad1.20x1.40mm_HandSolder
R12: 633k; R_0805_2012Metric_Pad1.20x1.40mm_HandSolder
R15: 2400 20%; R_0805_2012Metric_Pad1.20x1.40mm_HandSolder
R16: 1.5M; R_0603_1608Metric_Pad0.98x0.95mm_HandSolder
R17: 160k; R_0603_1608Metric_Pad0.98x0.95mm_HandSolder
R19: 34k 10%; R_1206_3216Metric_Pad1.30x1.75mm_HandSolder
R20, R24, R25, R27: 27k 5%; R_0805_2012Metric_Pad1.20x1.40mm_HandSolder
SI1: SOT-23-5_HandSoldering
SW1, SW5, SW6: RotaryEncoder_Bourns_Vertical_PEC12R-3x17F-Sxxxx
U1, U2: HV5622PG; PQFP-44_10x10mm_P0.8mm
U3: 4504; SOIC-16_ONS
U4, U14: CM1224-04MR; TSSOP-10_3x3mm_P0.5mm
U5: NCH6100HV; JST_EH_B4B-EH-A_1x04_P2.50mm_Vertical
U6: CAP1206-x-SL; SOIC-14_3.9x8.7mm_P1.27mm
U8: MCP1700x-330xxTT; SOT-23
U9: MAX98357A; TQFN-16-1EP_3x3mm_P0.5mm_EP1.23x1.23mm
U10, U12: NID5100; SC-74-6_1.55x2.9mm_P0.95mm
U11: TPS61040DBV; SOT-23-5
U13: STM32G0B1KEU6; UFQFPN-32-1EP_5x5mm_P0.5mm_EP3.5x3.5mm

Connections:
+3.3V: C2.2, C3.1, C6.1, C7.2, C25.1, C28.1, J7.4 (VDD), R5.2, R7.1, U3.1 (VCC), U4.3 (VP), U8.2 (VO), U10.1 (VDD)
+5V: C1.1, C4.1, C10.1, D3.1 (K), J2.2 (5V), L1.1, U8.3 (VI), U11.4 (EN), U11.5 (VIN), U14.3 (VP)
+12V: C8.1, C9.1, C18.1, C20.1, C23.1, C24.1, D2.1 (K), R15.2, R16.1, U1.27 (~POL), U1.30 (VDD), U2.27 (~POL), U2.30 (VDD), U3.16 (VDD), U5.3 (VIN)
+170V: C26.1, R19.2, R20.1, R24.1, R25.1, R27.1, U5.4 (HVOUT)
+V_CRIT: C17.1, C19.1, C21.1, C22.1, C29.1, C30.1, C31.1, C34.2, C35.1, C36.1, C37.1, J10.1 (VCC), R6.1, R13.1, R14.1, SI1.4 (Vdd), U6.7 (VDD), U9.2 (GAIN_SLOT), U9.7 (VDD), U9.8 (VDD), U10.6 (OUT), U12.6 (OUT), U13.4 (VDD/VDDA)
/AU_BCLK: U9.16 (BCLK), U13.32 (PB8)
/AU_DIN: U9.1 (DIN), U13.31 (PB7)
/AU_LRCLK: U9.14 (LRCLK), U13.18 (PA8)
/AU_~SD: R12.1, U13.17 (PB2)
/CAP_INT: R6.2, U6.3 (ALERT#), U13.16 (PB1)
/CAP_SCL: R14.2, U6.5 (SMCLK), U13.14 (PA7)
/CAP_SDA: R13.2, U6.4 (SMDATA), U13.13 (PA6)
/CC1: J2.4 (CC2), R4.1, U14.4 (CH2)
/CC2: J2.3 (CC1), R3.1, U14.1 (CH1)
/CLK: U1.28 (CLK), U2.28 (CLK), U3.6 (Cout)
/CS_IN1: J6.2, U6.2 (CS1)
/CS_IN2: J6.1, U6.13 (CS2)
/Din: U1.32 (DATA_IN), U3.12 (Eout)
/FB: C8.2, R16.2, R17.1, U11.3 (FB)
/GNDA: C15.2, C16.2, J11.4, R1.2, SW1.C
/GNDB: C13.2, C14.2, J12.3, SW6.C
/GNDC: C11.2, C12.2, J13.3, SW5.C
/HV_CLK: U3.7 (Cin), U13.27 (PB3)
/HV_DIN: U3.11 (Ein), U13.26 (PA15)
/HV_Vin1: J9.4, R27.2
/HV_Vin2: J9.3, R25.2
/HV_Vin3: J9.2, R24.2
/HV_Vin4: J9.1, R20.2
/HV_~BL: U3.9 (Din), U13.23 (PA12[PA10])
/HV_~LE: U3.3 (Ain), U13.30 (PB6)
/NCH_SHDN: U5.2 (SHDN), U13.8 (PA1)
/PB: C33.1, J11.1, SW1.S2
/ROT1A: J16.7, U13.29 (PB5)
/ROT1B: J16.6, U13.19 (PA9)
/ROT2A: J16.5, U13.20 (PC6)
/ROT2B: J16.4, U13.11 (PA4)
/ROT3A: J16.3, U13.21 (PA10)
/ROT3B: J16.2, U13.7 (PA0)
/ROT_1A: C14.1, J12.2, R26.2
/ROT_1B: C13.1, J12.1, R23.1
/ROT_2A: C16.1, J11.3, R29.2
/ROT_2B: C15.1, J11.2, R18.1
/ROT_3A: C11.1, J13.2, R21.2
/ROT_3B: C12.1, J13.1, R22.1
/SD_MISO: J7.7 (DAT0), U4.6 (CH3), U13.28 (PB4)
/SD_MOSI: J7.3 (CMD), U4.1 (CH1), U13.9 (PA2)
/SD_NSS: J7.2 (DAT3/CD), U4.4 (CH2), U13.15 (PB0)
/SD_SCK: J7.5 (CLK), U4.9 (CH4), U13.12 (PA5)
/SELECT_RET: J16.1, U13.10 (PA3)
/SP_OUT_N: LS1.2, U9.10 (OUTN)
/SP_OUT_P: LS1.1, U9.9 (OUTP)
/SW: D2.2 (A), L1.2, U11.1 (SW)
/SWCLK: J10.4 (SWCLK), U13.25 (PA14-BOOT0)
/SWDIO: J10.2 (SWDIO), U13.24 (PA13)
/~BL: U1.33 (~BL), U2.33 (~BL), U3.10 (Dout)
/~JTAG_RST: J10.3 (~RESET), U13.6 (PF2-NRST)
/~LE: U1.31 (~LE), U2.31 (~LE), U3.2 (Aout)
GND: BT1.2 (-), C1.2, C2.1, C3.2, C4.2, C6.2, C7.1, C9.2, C10.2, C17.2, C18.2, C19.2, C20.2, C21.2, C22.2, C23.2, C24.2, C25.2, C26.2, C27.2, C28.2, C29.2, C30.2, C31.2, C32.2, C34.1, C35.2, C36.2, C37.2, D1.1 (K), D3.2 (A), D4.1 (K), D5.1 (K), J2.1 (GND), J7.6 (VSS), J7.10 (SHIELD), J10.5 (GND), J16.8, R3.2, R4.2, R11.2, R17.2, SI1.1 (GND), SI1.2 (NC), SI1.3 (NC), U1.29 (VSS), U2.29 (VSS), U3.8 (VSS), U4.8 (VN), U5.1 (GND), U6.8 (GND), U6.9 (CS6), U6.10 (CS5), U6.11 (CS4), U6.12 (CS3), U8.1 (GND), U9.3 (GND), U9.11 (GND), U9.15 (GND), U9.17 (PAD), U10.2 (GND), U10.3 (_EN), U11.2 (GND), U12.2 (GND), U12.3 (_EN), U13.5 (VSS/VSSA), U14.8 (VN)
unnamed: BT1.1 (+), C27.1, C32.1, U12.1 (VDD)
unnamed: C33.2, R1.1, SW1.S1
unnamed: D1.2 (A), R5.1
unnamed: D4.2 (A), R15.1
unnamed: D5.2 (A), R19.1
unnamed: J1.1, U1.13 (HVOUT10)
unnamed: J1.2, U1.14 (HVOUT9)
unnamed: J1.3, U1.15 (HVOUT8)
unnamed: J1.4, U1.16 (HVOUT7)
unnamed: J1.5, U1.17 (HVOUT6)
unnamed: J1.6, U1.18 (HVOUT5)
unnamed: J1.7, U1.19 (HVOUT4)
unnamed: J1.8, U1.20 (HVOUT3)
unnamed: J1.9, U1.21 (HVOUT2)
unnamed: J1.10, U1.22 (HVOUT1)
unnamed: J3.1, U1.3 (HVOUT20)
unnamed: J3.2, U1.4 (HVOUT19)
unnamed: J3.3, U1.5 (HVOUT18)
unnamed: J3.4, U1.6 (HVOUT17)
unnamed: J3.5, U1.7 (HVOUT16)
unnamed: J3.6, U1.8 (HVOUT15)
unnamed: J3.7, U1.9 (HVOUT14)
unnamed: J3.8, U1.10 (HVOUT13)
unnamed: J3.9, U1.11 (HVOUT12)
unnamed: J3.10, U1.12 (HVOUT11)
unnamed: J4.1, U1.37 (HVOUT30)
unnamed: J4.2, U1.38 (HVOUT29)
unnamed: J4.3, U1.39 (HVOUT28)
unnamed: J4.4, U1.40 (HVOUT27)
unnamed: J4.5, U1.41 (HVOUT26)
unnamed: J4.6, U1.42 (HVOUT25)
unnamed: J4.7, U1.43 (HVOUT24)
unnamed: J4.8, U1.44 (HVOUT23)
unnamed: J4.9, U1.1 (HVOUT22)
unnamed: J4.10, U1.2 (HVOUT21)
unnamed: J5.1, U2.15 (HVOUT8)
unnamed: J5.2, U2.16 (HVOUT7)
unnamed: J5.3, U2.17 (HVOUT6)
unnamed: J5.4, U2.18 (HVOUT5)
unnamed: J5.5, U2.19 (HVOUT4)
unnamed: J5.6, U2.20 (HVOUT3)
unnamed: J5.7, U2.21 (HVOUT2)
unnamed: J5.8, U2.22 (HVOUT1)
unnamed: J5.9, U1.35 (HVOUT32)
unnamed: J5.10, U1.36 (HVOUT31)
unnamed: R18.2, SW1.B
unnamed: R21.1, SW5.A
unnamed: R22.2, SW5.B
unnamed: R23.2, SW6.B
unnamed: R26.1, SW6.A
unnamed: R29.1, SW1.A
unnamed: SI1.5 (Clk), U13.2 (PC14-OSC32_IN)
unnamed: U1.23 (DATA_OUT), U2.32 (DATA_IN)
unnamed: R11.1, U3.14 (Fin)
unnamed: R7.2, U3.13 (Select)
unnamed: R12.2, U9.4 (~SD_MODE)
unnamed: U10.5 (ST), U13.22 (PA11[PA9])

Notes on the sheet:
--------NC --NC --NC -----VDD -----GND --JTAG_RST -------EXTI0 -------GPIO ----SPI1_MOSI -------EXTI3 -------EXTI4 -----SPI1_SCK -----I2C2_SDA -----I2C2_SCL ---------NC -------EXTI1
I2S2_CK----- I2S2_SD----- GPIO------- EXTI5------- SPI1_MISO---- GPIO------- GPIO------ JTAG_CLK JTAG_IO----- GPIO--- GPIO---- EXTI10----- EXTI6------ EXTI9------ I2S2_WS----- I2S2_MCK----

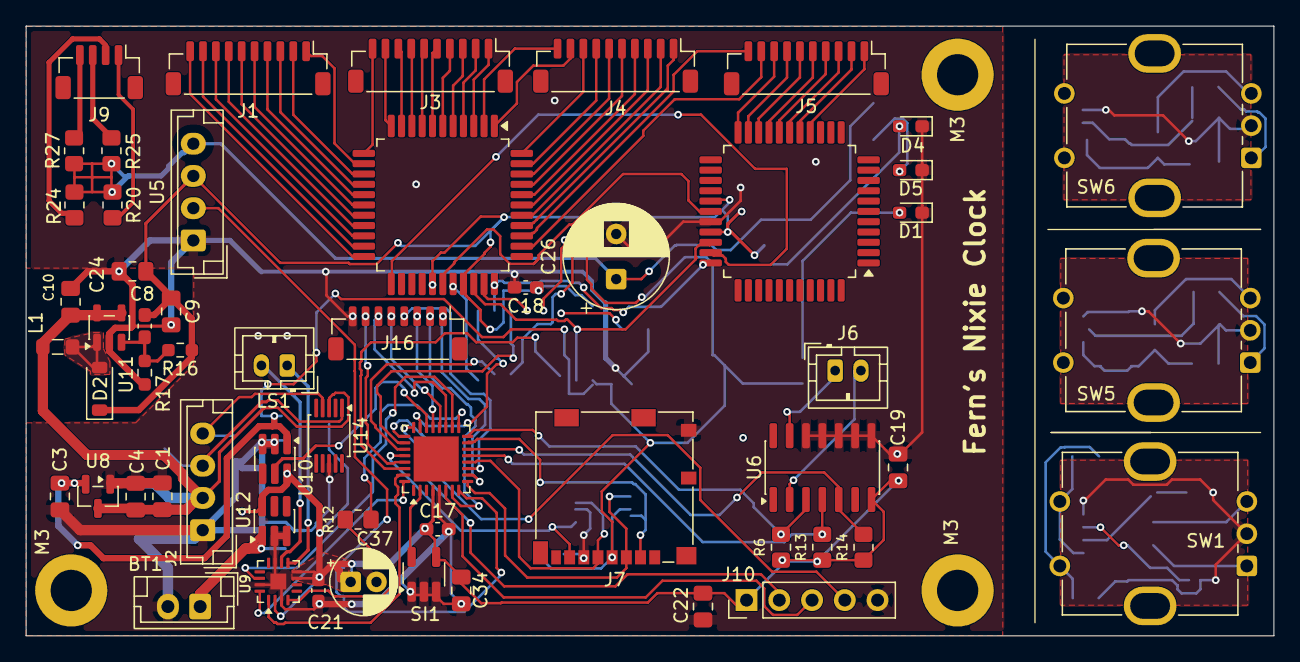
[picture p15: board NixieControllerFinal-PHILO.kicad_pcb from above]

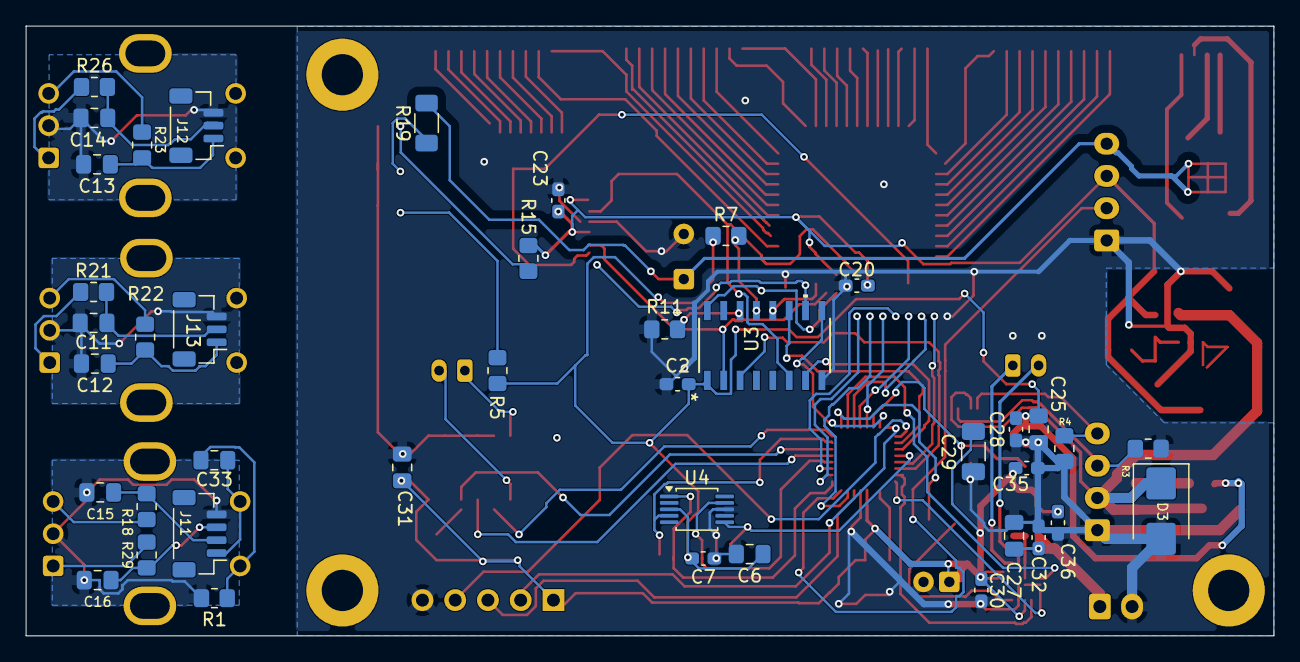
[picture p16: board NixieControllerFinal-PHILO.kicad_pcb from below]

Board: 2 copper layers, 96.8 x 47.3 mm, 98 parts (41 on the bottom side), 115 nets.

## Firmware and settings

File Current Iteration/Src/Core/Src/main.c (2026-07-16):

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
/* Includes ------------------------------------------------------------------*/
#include "main.h"
#include "dma.h"
#include "app_fatfs.h"
#include "i2c.h"
#include "i2s.h"
#include "rtc.h"
#include "spi.h"
#include "tim.h"
#include "usart.h"
#include "gpio.h"

/* USER CODE BEGIN Includes */
#include <stdbool.h>
#include <stdio.h> // used for DEBUG only
#include <string.h> // used for DEBUG UART handling
#include "debugging.h"
#include "cap1206.h"
#include "stm32g0xx_hal.h"
#include "UserInterface.h"
#include "SD_test.h"
#include "audio.h"

/* USER CODE END Includes */

/* USER CODE BEGIN PD */

#define ROT_TIMEOUT 3000	 // Switch timeout feature used to regulate rotary knob impulses (ms)
#define ROT_TIMEIN 0 // switch debounce time (ms)
#define ROT_COOLDOWN 0
#define SW_DEB 50 // time in ms used to debounce pushbutton
#define START_TIME 120000
#define OUTAGE_PIN_GROUP GPIOA
#define OUTAGE_PIN_NUM GPIO_PIN_4
/* USER CODE END PD */


/* USER CODE BEGIN PV */
volatile uint32_t FAILURE_CODES = 0; // songs.txt open failure |

/* USER CODE END PV */

void SystemClock_Config(void);
/* USER CODE BEGIN 0 */



typedef struct { // Used to measure the time of interrupt arrival in callback
	uint32_t A1;
	uint32_t A2;
	uint32_t B1;
	uint32_t B2;
	uint32_t C1;
	uint32_t C2;
	uint32_t SW;
} InterruptTable;

volatile InterruptTable intDataR; // R - Rising interrupt
volatile InterruptTable intDataF; // F - Falling interrupt
volatile int16_t interrupt_count = 0; // DEBUG


void interrupt_initializer(){ // Pre - intDataR and F are declared // Post - All values set to zero.
	intDataR.A1 = 0;
	intDataR.A2 = 0;
	intDataR.B1 = 0;
	intDataR.B2 = 0;
	intDataR.C1 = 0;
	intDataR.C2 = 0;
	intDataR.SW = 0;
	intDataF.A1 = 0;
	intDataF.A2 = 0;
	intDataF.B1 = 0;
	intDataF.B2 = 0;
	intDataF.C1 = 0;
	intDataF.C2 = 0;
	intDataF.SW = 0;
	USER_INT_REG0 = 0;
	USER_INT_REG1 = 0;
	USER_INT_REG2 = 0;
	USER_INT_REG3 = 0;
	USER_INT_REG4 = 0;
	USER_INT_REG5 = 0;
	USER_INT_REG6 = 0;
	USER_INT_REG7 = 0;
	LAST_ROTATION = 0;
	return;
}




void clock_init(){
	uint32_t start_time = START_TIME;
	start_time++;
}

#define NCH6100_SD_PORT GPIOA //NCH6100HV = 12V -> 170V DC -> DC converter
#define NCH6100_SD_PIN GPIO_PIN_1



void lowPowerMode(){
	printstr("\nEntering Low Power Mode.\n\r");
	HAL_GPIO_WritePin(NCH6100_SD_PORT, NCH6100_SD_PIN, GPIO_PIN_RESET);
	audio_mode = AUDIO_LOW_POWER; // set audio to play low power sound
	return;
}

void normalPowerMode(){
	printstr("Returning from LPM.\n\r");
			HAL_GPIO_WritePin(NCH6100_SD_PORT, NCH6100_SD_PIN, GPIO_PIN_SET);
			audio_mode = AUDIO_NORMAL; // set audio to play normally
}
/* USER CODE END 0 */

/**
  * @brief  The application entry point.
  * @retval int
  */
int main(void)
{

  /* MCU Configuration--------------------------------------------------------*/

  /* Reset of all peripherals, Initializes the Flash interface and the Systick. */
  HAL_Init();

  /* USER CODE BEGIN Init */
  interrupt_initializer();
  /* USER CODE END Init */

  /* Configure the system clock */
  SystemClock_Config();

  /* Initialize all configured peripherals */
  MX_GPIO_Init();
  MX_DMA_Init();
  MX_USART2_UART_Init();
  MX_I2S2_Init();
  if (MX_FATFS_Init() != APP_OK) {
    Error_Handler();
  }
  MX_I2C2_Init();
  MX_RTC_Init();
  MX_SPI1_Init();
  MX_TIM1_Init();
  /* USER CODE BEGIN 2 */
  // expect exti9_port == 0 for PA9
  //SD_Card_Test();
  printstr("hello!\n");
  FATFS fs;
  HAL_Delay(100);
  SD_init(&fs, &fn);
  playSound(40);
  /* USER CODE END 2 */

  /* Infinite loop */
  /* USER CODE BEGIN WHILE */
  //debugnote("hey guysssss");

  //f_mount(&fs, "0:", 1);

  //parsewavheader(&fil, &fmt1);

  while (1)
  {
    /* USER CODE END WHILE */

    /* USER CODE BEGIN 3 */

	  // Wait for user input, delay 250ms to save power.
	  HAL_Delay(250);
	  if ((USER_INT_REG0 | USER_INT_REG1 | USER_INT_REG2 | USER_INT_REG3 | USER_INT_REG4 | USER_INT_REG5 | USER_INT_REG6 | USER_INT_REG7) != 0){
		  user_interaction_mode();
	  }
	  if (HAL_GPIO_ReadPin(OUTAGE_PIN_GROUP, OUTAGE_PIN_NUM) == GPIO_PIN_SET)
	  {
	     lowPowerMode();
	  }

  }
  /* USER CODE END 3 */
}

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
/* USER CODE BEGIN 4 */
/* USER CODE BEGIN 4 */



void HAL_GPIO_EXTI_Rising_Callback(uint16_t GPIO_Pin){
	uint32_t t_ms;
	t_ms = HAL_GetTick();
	uint32_t t_elapsed_ms = 0;
	static volatile uint8_t *tail = NULL;
	if (USER_INT_REG7 == 0b0){ // determines current tail of interrupt buffer (Each bit corresponds to a given interrupt)
		tail = &USER_INT_REG7;
	}
	else if (USER_INT_REG6 == 0b0){
		tail = &USER_INT_REG6;
	}
	else if (USER_INT_REG5 == 0b0){
		tail = &USER_INT_REG5;
	}
	else if (USER_INT_REG4 == 0b0){
		tail = &USER_INT_REG4;
	}
	else if (USER_INT_REG3 == 0b0){
		tail = &USER_INT_REG3;
	}
	else if (USER_INT_REG2 == 0b0){
		tail = &USER_INT_REG2;
	}
	else if (USER_INT_REG1 == 0b0){
		tail = &USER_INT_REG1;
	}
	else if (USER_INT_REG0 == 0b0){
		tail = &USER_INT_REG0;
	}
	else {
		return;
	}


	switch(GPIO_Pin){
	// For any given interrupt (except PB):
	// 		Store time, set last falling interrupt time to zero.
	//		Determine time elapsed from (current time - time of last interrupt (of same type) occurring )
	// 		store interrupt pin in buffer

		case GPIO_PIN_0 :
			intDataR.A1 = t_ms;
			intDataF.A1 = 0;
			intDataF.A2 = 0;
			t_elapsed_ms = intDataR.A1 - intDataR.A2;
			*tail = 0b00000001;
			break;
		case GPIO_PIN_3 :
			intDataR.A2 = t_ms;
			intDataF.A1 = 0;
			intDataF.A2 = 0;
			t_elapsed_ms = intDataR.A2 - intDataR.A1;
			*tail = 0b00000010;
			break;
		case GPIO_PIN_1 :
			intDataR.B1 = t_ms;
			intDataF.B1 = 0;
			intDataF.B2 = 0;
			t_elapsed_ms = intDataR.B1 - intDataR.B2;
			*tail = 0b00000100;
			break;
		case GPIO_PIN_9 :
			intDataR.B2 = t_ms;
			intDataF.B1 = 0;
			intDataF.B2 = 0;
			t_elapsed_ms = intDataR.B2 - intDataR.B1;
			*tail = 0b00001000;
			break;
		case GPIO_PIN_10 :
			intDataR.C1 = t_ms;
			intDataF.C1 = 0;
			intDataF.C2 = 0;
			t_elapsed_ms = intDataR.C1 - intDataR.C2;
			*tail = 0b00010000;
			break;
		case GPIO_PIN_5 :
			intDataR.C2 = t_ms;
			intDataF.C1 = 0;
			intDataF.C2 = 0;
			t_elapsed_ms = intDataR.C2 - intDataR.C1;
			*tail = 0b00100000;
			break;
		case GPIO_PIN_6 :
		// The following is performed for the PB
		// 		determine time since last PB interrupt
		//		store time of current PB interrupt
		//		store interrupt pin in the buffer
		//		send PB signal if time since last rising AND falling PB interrupt is greater than the given threshold

			uint32_t t_elapsed_sw_msF = 0;
			uint32_t t_elapsed_sw_msR = 0;
			t_elapsed_sw_msF = t_ms - intDataF.SW;
			t_elapsed_sw_msR = t_ms - intDataR.SW;
			intDataR.SW = t_ms;
			*tail = 0b01000000;
			if ((t_elapsed_sw_msR > SW_DEB) && (t_elapsed_sw_msF > SW_DEB)  ){
				*tail = (*tail | 0b10000000);
				return;
			}
			else{
				*tail = 0;
				return;
			}
			break;
		default :
			break;
	}


	// Timing checks to reduce erroneous turning signals. Note - increasing ROT_TIMEOUT will result in undesirable behavior until the HAL_GetTick() surpases ROT_TIMEOUT. TIMEIN and COOLDOWN are currently set to zero.
	if ((t_elapsed_ms < ROT_TIMEOUT) && (t_elapsed_ms > ROT_TIMEIN) && ((t_ms - LAST_ROTATION) > ROT_COOLDOWN) ){
		*tail = (*tail | 0b10000000);
		LAST_ROTATION = t_ms;
	}
	else{
		*tail = 0;
	}
	return;
}

void HAL_GPIO_EXTI_Falling_Callback(uint16_t GPIO_Pin){
	uint32_t t_ms;
	t_ms = HAL_GetTick();
	uint32_t t_elapsed_ms = 0;

	static volatile uint8_t *tail = NULL;
	if (USER_INT_REG7 == 0b0){
		tail = &USER_INT_REG7;
	}
	else if (USER_INT_REG6 == 0b0){
		tail = &USER_INT_REG6;
	}
	else if (USER_INT_REG5 == 0b0){
		tail = &USER_INT_REG5;
	}
	else if (USER_INT_REG4 == 0b0){
		tail = &USER_INT_REG4;
	}
	else if (USER_INT_REG3 == 0b0){
		tail = &USER_INT_REG3;
	}
	else if (USER_INT_REG2 == 0b0){
		tail = &USER_INT_REG2;
	}
	else if (USER_INT_REG1 == 0b0){
		tail = &USER_INT_REG1;
	}
	else if (USER_INT_REG0 == 0b0){
		tail = &USER_INT_REG0;
	}
	else {
		return;
	}

	switch(GPIO_Pin){
	// For any given interrupt (except PB):
	// 		Store time, set last falling interrupt time to zero.
	//		Determine time elapsed from (current time - time of last interrupt (of same type) occurring )
	// 		store interrupt pin in buffer

		case GPIO_PIN_0 :
			intDataF.A1 = t_ms;
			intDataR.A1 = 0;
			intDataR.A2 = 0;
			t_elapsed_ms = intDataF.A1 - intDataF.A2;
			*tail = 0b00000001;
			break;
		case GPIO_PIN_3 :
			intDataF.A2 = t_ms;
			intDataR.A1 = 0;
			intDataR.A2 = 0;
			t_elapsed_ms = intDataF.A2 - intDataF.A1;
			*tail = 0b00000010;
			break;
		case GPIO_PIN_1 :
			intDataF.B1 = t_ms;
			intDataR.B1 = 0;
			intDataR.B2 = 0;
			t_elapsed_ms = intDataF.B1 - intDataF.B2;
			*tail = 0b00000100;
			break;
		case GPIO_PIN_9 :
			intDataF.B2 = t_ms;
			intDataR.B1 = 0;
			intDataR.B2 = 0;
			t_elapsed_ms = intDataF.B2 - intDataF.B1;
			*tail = 0b00001000;
			break;
		case GPIO_PIN_10 :
			intDataF.C1 = t_ms;
			intDataR.C1 = 0;
			intDataR.C2 = 0;
			t_elapsed_ms = intDataF.C1 - intDataF.C2;
			*tail = 0b00010000;
			break;
		case GPIO_PIN_5 :
			intDataF.C2 = t_ms;
			intDataR.C1 = 0;
			intDataR.C2 = 0;
			t_elapsed_ms = intDataF.C2 - intDataF.C1;
			*tail = 0b00100000;
			break;
		case GPIO_PIN_6 :
			// The following is performed for the PB
			// 		determine time since last PB interrupt
			//		store time of current PB interrupt
			//		store interrupt pin in the buffer
			//		send PB signal if time since last rising AND falling PB interrupt is greater than the given threshold

			uint32_t t_elapsed_sw_ms = 0;
			t_elapsed_sw_ms = t_ms - intDataR.SW;
			intDataR.SW = t_ms;
			if (t_elapsed_sw_ms > SW_DEB){
				return;
			}
			else{
				*tail = 0;
				return;
			}
			break;
		default :
			break;
	}



	// Timing checks to reduce erroneous turning signals. Note - increasing ROT_TIMEOUT will result in undesirable behavior until the HAL_GetTick() surpases ROT_TIMEOUT. TIMEIN and COOLDOWN are currently set to zero.
	if ((t_elapsed_ms < ROT_TIMEOUT) && (t_elapsed_ms > ROT_TIMEIN) && ((t_ms - LAST_ROTATION) > ROT_COOLDOWN) ){
		*tail = (*tail | 0b10000000);
		LAST_ROTATION = t_ms;
	}
	else{
		*tail = 0;
	}
	return;
}



void HAL_SYSTICK_Callback(void)
{
  disk_timerproc();
  return;
}


/* USER CODE END 4 */
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


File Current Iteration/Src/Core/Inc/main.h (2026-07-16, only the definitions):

#define B1_Pin GPIO_PIN_13
#define B1_GPIO_Port GPIOC
#define B1_EXTI_IRQn EXTI4_15_IRQn
#define MCO_Pin GPIO_PIN_0
#define MCO_GPIO_Port GPIOF
#define USART2_TX_Pin GPIO_PIN_2
#define USART2_TX_GPIO_Port GPIOA
#define USART2_RX_Pin GPIO_PIN_3
#define USART2_RX_GPIO_Port GPIOA
#define GPIO_SD_CS_Pin GPIO_PIN_0
#define GPIO_SD_CS_GPIO_Port GPIOB
#define TMS_Pin GPIO_PIN_13
#define TMS_GPIO_Port GPIOA
#define TCK_Pin GPIO_PIN_14
#define TCK_GPIO_Port GPIOA

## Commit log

2026-01-30 Enhance README with project details and development status
    Expanded the README to include detailed sections on wiring/programming, PCB, and enclosure development.
2026-02-04 Repo cleanup and code update
    [NixieController.kicad_pcb, NixieController.kicad_sch, NixieControllerFinal-PHILO.kicad_pcb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]
2026-02-10 Working SPI protocol, SD reading, OS development
    [NixieControllerFinal-PHILO.kicad_sch]
2026-02-11 readme update and schematic cleanup
    [NixieControllerFinal-PHILO.kicad_pcb]
2026-02-12 Organization and CAD files
    [NixieControllerFinal-PHILO.kicad_pcb, NixieControllerFinal-PHILO.kicad_sch]
2026-02-12 Corrupted project files fix
    [FATFS_SD.c, FATFS_SD.h, SD_test.c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]
2026-02-12 Update BOM status in README
    Clarified the status of the BOM in the README.
2026-06-13 repo refresh
    [Enclosure.SLDASM, NixieControllerFinal-PHILO.kicad_pcb, NixieControllerFinal-PHILO.kicad_sch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]
2026-06-21 Latest PCB revision
    [NixieControllerFinal-PHILO.kicad_pcb, NixieControllerFinal-PHILO.kicad_sch, logicAnalyzer.kicad_pcb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]
2026-06-21 Update Todo list with oscillator/RTC module
    Added oscillator/RTC module incorporation to PCB and schematic todos.
2026-06-21 Update and rename Hardware BOM (WIP) to PCB_BOM_WIP).csv
    [PCB_BOM_WIP).csv]
2026-06-21 Update and rename Enclosure BOM (WIP) to Enclosure_BOM_WIP.csv
    [Enclosure_BOM_WIP.csv]
2026-06-21 Fix formatting in Enclosure_BOM_WIP.csv
    [Enclosure_BOM_WIP.csv]
2026-06-23 Enhance README with schematic and enclosure previews
    Added schematic, block diagram, PCB, and enclosure previews to README.
2026-07-09 Updated PCB and Layout
    [NixieControllerFinal-PHILO.csv, NixieControllerFinal-PHILO.kicad_pcb, NixieControllerFinal-PHILO.kicad_sch]
2026-07-09 Revise README for project updates and clarity
    Updated README to reflect current project status and details.
2026-07-16 Updated Readme with improved firmware documentation/updated src code
    [NixieControllerFinal-PHILO.kicad_pcb, NixieControllerFinal-PHILO.kicad_sch]
2026-07-16 Revise README with integration updates and new notes
    Updated integration section and added new development notes for Nixie driver control logic, low-power handling, and RTC implementation.

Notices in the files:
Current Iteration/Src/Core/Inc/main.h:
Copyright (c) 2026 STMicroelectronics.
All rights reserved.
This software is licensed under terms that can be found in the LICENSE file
